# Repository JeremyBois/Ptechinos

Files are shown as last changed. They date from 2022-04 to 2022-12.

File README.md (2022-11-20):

# Ptechinos
## Description
**Ptechinos** is an ergonomic keyboard inspired by [Pteron36](https://github.com/harshitgoel96/pteron36-split-keyboard) and [Balbuzard](https://github.com/brow/balbuzard):

**Hardware**

  - 36 keys (Kailh choc v1)
    - 5x3 keys layout + 3 thumb keys
    - 2 optional encoders (EVQWGD001) or keys (36 --> 38)
      - Top pinky
      - Above thumbs
    - Outer columns for top pinky
      - L size movement reduce hand torsion
      - Top pinky still available (key or encoder)
    - Small splay to adjust to natural hand shape
    - Columns stagger with extreme pinky stagger

  - Modular
    - I2C components
      - Trackpad (GlidePoint Cirque Trackpad TM035035)
      - OLED screen (Adafruit OLED SSD1306 Monochrome 1.3" 128x64)
      - Any I2C device (like SparkFun Qwiic COM-15168)
        - Interface 1: Qwiic connection
        - Interface 2: Header pins exposed (1x04 with 2.54mm pitch)
    - SPI components (RP2040 only)
      - Trackball (Pixart PMW3360, 25mm ball used)
      - Any SPI device: header pins exposed (2x04 with 1.27mm pitch)

    - Pogo (magnetic) or TRRS to connect both halves
      - TRRS: More option but not safe (shorts, hard to disconnect in case of tear-out)
      - Pogo: Less option but safe (no shorts, safely disconnect in case of tear-out)

    - Split or Unsplit
      - Use magnetic Pogo pins and a central module

  - Bluetooth ready
    - On/Off switch to avoid losing battery
    - JST PH connectors to make it easy to replace the battery
    - MCU board footprint compatible with *Nice!nano* and like
    - Components support is ZMK dependent

**Software**

  - [QMK layout v0.5](https://github.com/JeremyBois/qmk-ptechinos)

***
**Drawings and 3D case design made with love by [pandhara](https://www.artstation.com/pandhara).**
***

# Versions
All production files are in `data/production` :
  - `gerber`: files needed to manufacture the keyboard PCB
  - `plates`: 2D/3D files to build the **sandwich** case
  - `unibody`: 2D/3D files to build the **3D** case (starting from v0.6)

## V0.6 - 🚧

**WORK IN PROGRESS.**

### Changes

  - **PCB**
    - Improve / clean routing
    - Dimensions (hxl): 111x159mm
    - Choc v1 spacing (with 1mm padding)
    - Add support for Serial components:
      - Trackball (Pixart PMW3360)
    - Add support for I2C components:
      - Cirque trackpad with FFC/FPC connector
      - OLED with socketing / QWIIC (Require KP2040)
      - Joystick with QWIIC (Require KP2040)
    - Update guard holes position and add another at the bottom (3 in total)
    - MCU and TRRS are now aligned to PCB top edge and each protrude slightly
    - Add support for [Asymplex ChicagoSteno T15 Thumb](https://www.asymplex.xyz/product/cs-ergo-sets)
      - Change right/left thumbs orientation (+-90°)
      - Increase spacing between thumbs (+5mm)
      - Reduce rotation between thumbs (-5°)
    - Encoders
      - Thumb encoder pins connection change (F5/F4 to D4/C6)
      - Index encoder at the top left as an alternative to thumb encoder
      - Both encoders can be used at the same time
    - Make more space for encoder / optional key for MX keycaps (using [this adapter](https://www.thingiverse.com/thing:4504072))
    - Add Pogo connectors support
      - 4 pins version allows for safer alternative to TRRS (no shorts, disconnect gently)
      - 8 pins version allows to switch between split and unsplit

  - **Sandwich case**
    - Bottom plate
      - Uses 15cm magnet holes
      - Replace standard 1/4 holes by splitkb tenting kit hole
    - Top plate
      - Encoder / Key (above thumbs cluster) excluded from plate

  - **Unibody case**  (WORK IN PROGRESS)
    - 3D case
    - Support for different modules:
      - OLED Adafruit OLED SSD1306 Monochrome (1.3 "128x64)
      - Trackpad GlidePoint Cirque Trackpad TM035035 (35mm flat)
      - Trackball Pixart PMW3360 (25mm ball)
      - Unsplit both parts (Pogo connectors)
      - Bottom plate with 1/4inches and magnets to connect to camera mounts
        - Plate stays on the mount
        - Keyboard clip with magnet to the plate

  - **Misc**
    - Add bill of material (BOM)
    - Add documentation about parts

Left           |  Right
:-------------------------:|:-------------------------:
Left  |  Right

Electrical schema

Orientation

### Bill of materials (BOM)
#### Base
Part name | Amount | Reference sourced | Notes | Links
:------------------------|:-------------------------:|:-------------------------:|:-------------------------|:-------------------------
PCB  | 2 | | See `data/production/v0.6/gerber` folder | [PCBWay](https://www.pcbway.com/), [JLCPCB](https://jlcpcb.com/), ...
*(Optional)* Hot Swap Sockets | 36 | Kailh Choc hotswap sockets | Choc version only | [Splikb](https://splitkb.com/collections/keyboard-parts/products/kailh-hotswap-sockets?variant=39472161456205)
Diodes | 38 | 1N4148_SOD-123 | You can either use through hole or surface mount diodes (SMD) | [Splitkb](https://splitkb.com/collections/keyboard-parts/products/smd-diodes)
Kailh Choc switch | 36 (38) | PG1350 | Only choc switches not MX | [Splitkb](https://splitkb.com/collections/switches-and-keycaps/products/kailh-low-profile-choc-switches)
Encoder horizontal | 1/2 | Panasonic_EVQWGD001 | Both sides on QMK and only the master side on ZMK | [Aliexpress](https://fr.aliexpress.com/item/1005003613012575.html)
*(Optional)* Tactile push button | 1/2 | 1TS002A-2500-4300 | Can be replaced with a pair of tweezer or using on board push buttons if any | [Splitkb](https://splitkb.com/collections/keyboard-parts/products/reset-buttons?variant=42291963527427)
*(Optional)* Tenting puck | 1/2 | Splitkb_TentingPuck | 1/4th inch threaded tripod mounting hole | [Splitkb](https://splitkb.com/products/tenting-puck)

#### Bluetooth
Part Name | Amount | Reference sourced | Notes | Links
:------------------------|:-------------------------:|:-------------------------:|:-------------------------|:-------------------------
Battery | 2 | DEAH 301030 | This size could fit under the microcontroller but be free to order another one | [Aliexpress](https://fr.aliexpress.com/item/1005003635594999.html)
*(Optional)* On/Off switch | 2 | TLZWLA_MSK22D18<br>NewRise_MSS22D18 | Allow to turn off the battery power drain during transport | [Aliexpress](https://fr.aliexpress.com/item/4000681551007.html)<br>[Aliexpress](https://fr.aliexpress.com/item/32819941320.html)
*(Optional)* Battery JST PH connector | 0/1/2 | S2B-PH-K-S(LF)(SN) | You can also solder the battery directly to the pins of the PCB | [Splitkb](https://splitkb.com/products/wireless-controller-expansion-bundle)
Nice!nano | 2 | | Cannot be used with QMK due to license issues but works with ZMK | [Splitkb](https://splitkb.com/collections/keyboard-parts/products/nice-nano)
*(Optional)* Decoupling capacitor 4.7uF | 2 | Samsung Electro-Mechanics CL21A475KPFNNNE  | The capacitors mitigate power surge when turning on the battery (already present on Nice!nano boards) | [Mouser](https://eu.mouser.com/ProductDetail/Samsung-Electro-Mechanics/CL21A475KPFNNNE?qs=yOVawPpwOwmSlN4VFiPp3g%3D%3D)

#### Wired
Part Name | Amount | Reference sourced | Notes | Links
:-------------------------|:-------------------------:|:-------------------------:|:-------------------------|:-------------------------
TR(R)S cable | 1 | TRRS | Both TRS or TRRS will work but only tested with a TRRS | [Splitkb](https://splitkb.com/collections/keyboard-parts/products/braided-trrs-cable)
TRRS connectors  | 2  | PJ-320A | | [Splikb](https://splitkb.com/collections/keyboard-parts/products/trrs-jacks)
MCU board with ProMicro footprint | 0/2 | Adafruit_KP2040-RP2040 | ProMicro ATmega32u4 (AVR) <br>EliteC ATmega32u4 (AVR)<br>SparkFun Pro Micro - RP2040 (ARM)<br>Adafruit KP2040 - RP2040 (ARM) | [Splitkb](https://splitkb.com/collections/keyboard-parts/products/pro-micro-atmega32u4-5v-16mhz)<br>[Splitkb](https://splitkb.com/collections/keyboard-parts/products/elite-c-low-profile-rev4-microcontroller)<br>[Mouser](https://eu.mouser.com/ProductDetail/SparkFun/DEV-18288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)<br>[Adafruit](https://www.adafruit.com/product/5302)

#### Trackpad
Part Name | Amount | Reference sourced | Notes | Links
:-------------------------|:-------------------------:|:-------------------------:|:-------------------------|:-------------------------
Cirque trackpad | 1/2 | Cirque_TM035035-2024-002 | Unibody case required 35mm version but any size would work on the sandwich case | [Mouser](https://eu.mouser.com/ProductDetail/355-TM0350352024-002)
FFC jumper cable | 1/2 | Molex_15166-0123 | One on each side where a trackpad is added | [Mouser](https://eu.mouser.com/ProductDetail/538-15166-0123)
FPC connector | 1/2 | GCT_FFC2B35-12-G | One on each side where a trackpad is added | [Mouser](https://eu.mouser.com/ProductDetail/640-FFC2B35-12-G)
4.7kΩ Resistor (I2C) | 2/4 | Panasonic_ERA-6AEB472V | 2 Pull-up resistors for I2C connection are required at least on the master side | [Mouser](https://eu.mouser.com/ProductDetail/667-ERA-6AEB472V)

#### OLED screen
Part Name | Amount | Reference sourced | Notes | Links
:-------------------------|:-------------------------:|:-------------------------:|:-------------------------|:-------------------------
SSD1306 OLED 128x32 | 1/2 | | Works with both ARM and AVR MCU on QMK | [Splitkb](https://splitkb.com/collections/keyboard-parts/products/oled-display?variant=31716335616077)
4.7kΩ Resistor (I2C) | 2/4 | Panasonic_ERA-6AEB472V | 2 Pull-up resistors for I2C connection are required at least on the master side | [Mouser](https://eu.mouser.com/ProductDetail/667-ERA-6AEB472V)

#### 3D case
Part Name  | Amount | Notes | Links
:-------------------------|:-------------------------:|:-------------------------|:-------------------------
Top plate | 2 | See `data/production/v0.6/unibody` folder for DXF / STL files |
3D Case (left) | 1 | See `data/production/v0.6/unibody` folder for DXF / STL files |
3D Case (right) | 1 | See `data/production/v0.6/unibody` folder for DXF / STL files |
M2 Screws | 16 |  For M2 spacers | [Splitkb](https://splitkb.com/products/m2-screws?variant=42429972709635)
M2 Case Spacers | 10 | 6mm works fine (PCB = 1.6mm, PCB to switch  = 2.2mm, socket = 1.8mm) | [Splitkb](https://splitkb.com/products/brass-m2-spacers?_pos=2&_sid=9df1e01bc&_ss=r)
M2 Guard Spacers | 6 | TODO |

#### Sandwich case
Part Name  | Amount | Notes | Links
:-------------------------|:-------------------------:|:-------------------------|:-------------------------
Top plate  | 2 | See `data/production/v0.6/plates` folder for DXF / STL files |
Bottom plate  | 2 | See `data/production/v0.6/plates` folder for DXF / STL files |
M2 Screws | 16 |  For M2 spacers | [Splitkb](https://splitkb.com/products/m2-screws?variant=42429972709635)
M2 Case Spacers | 10 | 4/6mm works fine depending of the length of used M2 screws| [Splitkb](https://splitkb.com/products/brass-m2-spacers)
M2 Guard Spacers | 6 | TODO |

## V0.5 - ✅

  - Update Ergogen config
    - automatic plates generation (2d/3d)
    - remove PCB components (unused)
    - add bottom magnets / camera mounts holes
    - add preview drawing to make easier to visualize plates stack
  - Update PCB board constraints with more aggressive minimums
  - Update PCB according to new Ergogen plate config
  - PCB
    - Improve silkscreens adjustments
    - More aggressive thumb angle
    - Lower thumbs keys
    - Encoder angle is now the same as the thumb key below
    - Update board dimensions
  - Bottom plate uses 15cm magnet holes

Left           |  Right
:-------------------------:|:-------------------------:
Left  |  Right

Electrical schema

Orientation

**Wired version is fully tested** : see used [QMK layout](https://github.com/JeremyBois/qmk-ptechinos).

## V0.4 - ⚰️

  - Update README
    - Add credits
    - Add pictures
    - Add notes for available mask colors
  - Update silkscreen drawings with final version
  - Consistent hole size in switch footprints
  - Generate STL files for plate mounting
  - Make encoder (EVQWGD001) footprint reversible using SMD jumpers
    - Require to bridge jumpers on the same side as the encoder
  - Bottom plate uses 10cm or 15cm magnet holes

**Untested.**

## V0.3 - ⚰️

  - Replace vertical encoder (EC11) with horizontal one (EVQWGD001)
  - Better tracing
  - Add teardrops
  - Mounting
    - Correct mounting holes size
    - Add MCU guard holes
    - Complete plates (top / bottom)
  - Add logo to silkscreen (draft)
  - Find keyboard name
  - Bottom plate uses 10cm magnet holes

**Untested.**

## V0.2 - ⚰️

  - Add Bluetooth components
    - On/off switch
    - Capacitor
    - Battery support
      - JST female to avoid to solder the battery
      - pins also available if soldering is needed/wanted
  - Mounting
    - Add Mounting holes (draft)
    - Add plates (draft)

**No production files.**

## V0.1 - ⚰️

  - 36 keys + 2 optional encoders (EC11)
  - Pro micro footprint
  - TRRS / TRS jack to connect both halves
  - Reset

**No production files.**

# Notes
## v0.5 VS v0.6
Distance              | v0.6            | v0.5             | Result    |
|---------------------|-----------------|------------------|-----------|
Top to FarThumbs      | [69.31, 88.91]  | [70.905, 93.735] |  [✅, ✅] |
Top to InnerThumbs    | [28.970, 67.89] | [31.885, 72.075] |  [✅, ✅] |
Encoder to HomeThumbs | [ , 3.432]      | [ ,    4.096]    |  [  , 😑] |
Top to OuterPinky     | [58.57, 37.64]  | [59.665, 40.315] |  [✅, ✅] |
Home to HomeThumbs    | [30.11, 52.55]  | [32.246, 54.7]   |  [✅, ✅] |

## v0.5 VS v0.66
Distance              | v0.66            | v0.5             | Result    |
|---------------------|-----------------|------------------|-----------|
Top to FarThumbs      | [70.04, 87.98]  | [70.905, 93.735] |  [✅, ✅] |
Top to InnerThumbs    | [28.83, 67.71]  | [31.885, 72.075] |  [✅, ✅] |
Encoder to HomeThumbs | [ , 3.556]      | [ ,    4.096]    |  [  , 😑] |
Top to OuterPinky     | [57.54, 37.07]  | [59.665, 40.315] |  [✅, ✅] |
Home to HomeThumbs    | [30.456, 52.97] | [32.246, 54.7]   |  [✅, ✅] |

### TODO

  - [x] RP2040 MCU board in a ProMicro footprint
    - More SRAM to enable more stuff (RGB leds, pointing devices, OLED, ...)
    - Better pointing device experience ([smoother trackpad experience](https://www.reddit.com/r/ErgoMechKeyboards/comments/w6r7on/comment/ihfko44/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))
    - **QWIIC** connector for easy to plug I2C devices
    - [x] Find headers perfect height

  - [x] GlidePoint Cirque circular trackpad (I2C)
    - [Secifications](https://www.dropbox.com/s/2l2cywvwxdfnoyw/GP-DS-170409%20TM035035%20SPI-I2C%20PINN%20Trackpad%20Spec.pdf?dl=0)
    - [Schematic](https://www.dropbox.com/s/vk752nkoqo7jbqw/02-000611-00RevA01_TM035035-2024-000_SCH.pdf?dl=0)
    - Trackpad PCB must be adapted to be used with Elite-C MCU
      - Remove **R1** (SPI --> I2C)
      - Remove **R7** and **R8** (3.3V --> 5V VCC)
    - Trackpad PCB must be adapted to be used with KB2040 MCU
      - Remove **R1** (SPI --> I2C)
    - [x] Clear enough space to make possible to use both FFC and Qwiic connectors
    - [x] Make sure pin assignation on FFC connector is correct

  - [x] OLED support (I2C)
    - [QMK support](https://docs.qmk.fm/#/feature_oled_driver?id=basic-configuration)
    - [SSD1306 Monochrome 1.3" 128x64 - QWIIC](https://www.adafruit.com/product/938)
    - [SSD1306 Monochrome 0.96" 128x64 - pins](https://splitkb.com/products/oled-display?variant=31226608549965)
    - [SSD1327 Grayscale 1.5" 128x128 - QWIIC (RP2040 required and no QMK support)](https://www.adafruit.com/product/4741)
    - [x] Qwiic accessible
    - [x] Header pins accessible

  - Bluetooth
    - [x] Remove `VCC_ON` (was used to isolated `VCC` line but most MCU have this as a software feature)
    - [x] Remove redundant B+ and B- pins (ones on the connector foo)
    - [x] Make sure there is enough place for battery JST

  - Pogo
    - [x] Add Pogo magnetic connectors (4 pins) as an alternative for TRRS
      - Can be used to merge both half to create an unsplit keyboard
    - [x] Find Pogo connector (4 pins)
    - [x] Find Pogo connector (8 pins)
    - [x] Check 3D works (unibody case)
      - Works (tested with 4 pins version)

  - PCB indications / information
    - Solder on the bottom side
      - Resistors
      - Capacitor
      - Reset switch
      - Diodes
      - Hotswaps
    - [x] Drawings on silkscreen should be more uniform on stroke thickness

  - Trackball
    - [x] Move Reset below Pogo to make space for SPI interface
    - [x] Add SPI interface (in place of Reset) (8 pins header column)
    - [x] Add SPI interface (8 pins JST SH vertical)
    - [x] Check 3D works (unibody case)
    - [x] Update footprint for sensor
    - Limitations of existing boards
      - Only works with the right side with vertical header
      - Can works on all side if using right angle header (add header width to trackball height ...)

  - Documentation
    - [x] Update reset switch
    - [x] Add missing
      - [x] Resistors
      - [x] Capacitors
      - [x] Pogo
      - [x] Header pins PCB
      - [x] Header pins Trackball
    - [ ] Add Build logs
    - [ ] Add Wiki

  - Software
    - [ ] Handle difference between RP2040 and Atemega32U4 on QMK side
      - Trackball (SPI) only compatible with RP2040

  - Outputs (v0.68)
    - [x] Update PCB / Schema date
    - [x] Regenerate DXF (mm)
    - [x] Regenerate gerbers (inch)
    - [x] Regenerate previews
    - [x] Push gerbers for v0.6 (the ones sent to production)

  - Try
    - [x] [Choc keycaps tilter](https://www.thingiverse.com/thing:5379000)
    - [x] Create [Choc keycaps tilter](https://www.thingiverse.com/thing:5379000) variant with 90° angle (to test on outer pinky)
    - [x] [chicago stenographer](https://www.asymplex.xyz/product/cs-chicago-stenographer-profile) keycaps
    - [x] **QWIIC** as a hotswapable I2C with integrated pull-up resistors
    - [ ] Female Threaded 1/4" Standoffs in Unibody case instead of Splikb tenting puck (smaller hole ...)
    - [ ] [Choc to MX converter](https://www.thingiverse.com/thing:4504072) with custom artisan

## Kicad errors

  - Courtyard FPC connector and jumpers overlap
    - It's ok because both are not used at the same time

  - Courtyard JST PH (bluetooth) and JST SH (trackball) overlap
    - It's ok because both are not used at the same time

  - FPC pins are not connected
    - It's ok because we only use 4 of them (I2C)

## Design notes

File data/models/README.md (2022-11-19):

# CAD models

  - [Diode_1N4148W_SOD123](https://grabcad.com/library/sod123-1)
  - [Capacitor_0805_0.6mm](https://grabcad.com/library/ceramic-capacitor-0805-2012-1)
  - [Resistor_0805](https://grabcad.com/library/resistor-0805-1)
  - [JST_PH_2pins_RightAngle](https://grabcad.com/library/2-pin-jst-connector-right-angle-1)
  - [JST_SH_8pins_Vertical](https://grabcad.com/library/jst-sh-smd-connectors-1)
  - [Pogo_4pins_RightAngle](https://grabcad.com/library/4-pin-magnetic-connector-1)
  - [Pogo_8pins_RightAngle](https://grabcad.com/library/pogo-pin-1)
  - [Switch_AlpsAlpine_SKRKAE](https://tech.alpsalpine.com/j/products/detail/SKRKAEE020/)
  - [Encoder_Panasonic_EVQWGD001](https://grabcad.com/library/panasonic-evqwgd001-encoder-1)
  - [Adafruit_KB2040](https://learn.adafruit.com/adafruit-kb2040/downloads)
  - [TRRS_3.5mm](https://grabcad.com/library/3-5mm-micro-jack-female-trrs-fc68128-connector-audio-1)
  - [Kailh_choc_Hotswap](https://github.com/perigoso/keyswitch-kicad-library/tree/main/source_3d/Switch_Keyboard_Kailh)
  - [Kailh_Choc_V1](https://github.com/perigoso/keyswitch-kicad-library/tree/main/source_3d/Switch_Keyboard_Kailh)
  - [FPC_connector](???)

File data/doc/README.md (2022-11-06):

# Documentation

## Whislist

  - Trackball
    - [x] Ball 25mm
    - [x] Bearing balls 2.5mm zirconium oxide (G5)
    - [x] JST SH connector
    - [ ] Breakout board
      - [3.3V or 5V](https://github.com/Ariamelon/Ogen)
      - Assembly JLCPCB
      - Sensor on aliexpress

  - Others
    - [x] Reset
    - [x] Capacitor
    - Rounded socket strip female (~4.8)

  - Pogo
    - [x] 4 pins magnetic
    - [x] 8 pins

## Case

  - [Trackpad + keyboard](https://www.troykitch.com/2021/06/05/split-keyboard-base.html)
  - [Laptop + keyboard](https://www.reddit.com/r/ErgoMechKeyboards/comments/xkdqk0/split_keyboard_attached_to_roost_stand/)
  - Trackball
   - [Oddball](https://github.com/atulloh/oddball)
   - [Ximi](https://www.reddit.com/r/ErgoMechKeyboards/comments/xhvq3v/ximi_is_near/)
   - [Orb](https://github.com/dpapavas/orb-trackball)
   - [Norne v3](https://www.reddit.com/r/ErgoMechKeyboards/comments/y88hbm/my_attempt_to_make_keyboarding_just_a_bit_weirder/)
  - Tenting
    - [Magnetic legs / case](https://www.reddit.com/r/ErgoMechKeyboards/comments/y1a0iy/new_travel_keyboard_this_time_its_splayed/)
    - [Some examples](https://rmwphd.github.io/tenting.html)

## RP2040

  - QMK
    - [Conversion from Promicro (cocot46plus)](https://zhan.co.nl/posts/2022-08-24-cocot46plus-build-notes/#converting-to-rp2040)
    - [Conversion from Promicro (gherkin)](https://learn.adafruit.com/using-qmk-on-rp2040-microcontrollers?view=all)

  - Trackball
    - [Nano trackball + lot of projects / 3D](https://github.com/jfedor2/rp2040-pmw3360)

## Components
### Adafruit KB2040
  - [Product](https://www.adafruit.com/product/5302)

  - [Tutorial](https://learn.adafruit.com/adafruit-kb2040)

  - QMK support
    - [Pull request](https://github.com/qmk/qmk_firmware/pull/14877)

  - Builds
    - [Unichunky](https://www.reddit.com/r/ErgoMechKeyboards/comments/wizqo8/the_unichunky/)

### Trackball Pixart PMW3360 Motion sensor
  - Breakout board
    - [PMW3360](https://www.tindie.com/products/jkicklighter/pmw3360-motion-sensor)

  - PCB
    - [3.3V](https://github.com/jfedor2/pmw3360-breakout)
    - [3.3V or 5V](https://github.com/Ariamelon/Ogen)
    - [Circular - Charybdis keyboard](https://github.com/Bastardkb/charybdis-pmw-3360-sensor-pcb)

  - Capteur
    - [PMW3360DM-T2QU + Lens](https://aliexpress.com/item/32834829893.html)
    - [PMW3360DM-T2QU + Lens](https://aliexpress.com/item/33056166849.html)
    - [PMW3389DM-T3QU + Lens](https://aliexpress.com/item/32891335998.html)

  - Bearing ball ([Zr02 seems better than Si3n4](https://prokcssmedia.blob.core.windows.net/sys-master-images/hb2/haf/9263251816478/ceramic-bearing-selection-guide.pdf), G5 > G10)
    - [ZrO2  | G5 | 2.5mm](https://aliexpress.com/item/4000852337622.html)
    - [Si3N4 | G5 | >=1.0mm](https://aliexpress.com/item/1005004242351539.html)

  - Ball
    - [25mm | billiard](https://www.amazon.com/CAOREN-16pcs-Billiard-Children-Accessories/dp/B0836WQQF5)
    - [34mm | ](https://www.amazon.fr/Perixx-PERIPRO-303-GBK-34mm-Trackball/dp/B08DD6GQRV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)
    - [25mm | stones](https://aliexpress.com/item/1005003604499161.html)

  - CAD
    - [Oddball project](https://github.com/atulloh/oddball)
      - PMW3360 cover
      - Bearing mount
    - [Orb](https://github.com/dpapavas/orb-trackball)
      - [reddit](https://www.reddit.com/r/ErgoMechKeyboards/comments/xziw1u/the_orb_a_parametric_trackball_with_btu_mounted/)
      - PMW3389 cover
      - Bearing mount
      - Compact with buttons

### GlidePoint Cirque Trackpad TM035035
  - QMK support
    - [Trackpad](https://github.com/qmk/qmk_firmware/blob/master/docs/feature_pointing_device.md)
    - [I2C wiring](https://docs.qmk.fm/#/feature_split_keyboard)
    - Trackpad PCB must be adapted to be used with KB2040
      - Remove **R1** (SPI --> I2C)

  - Documentation
    - [Secifications](https://www.dropbox.com/s/2l2cywvwxdfnoyw/GP-DS-170409%20TM035035%20SPI-I2C%20PINN%20Trackpad%20Spec.pdf?dl=0)
    - [Schematic](https://www.dropbox.com/s/vk752nkoqo7jbqw/02-000611-00RevA01_TM035035-2024-000_SCH.pdf?dl=0)

  - Builds
    - [On corne](https://beekeeb.com/cirque-trackpad-i2c-on-corne-keyboard/)
    - [On Chunky V2](https://kbd.news/Chunky-V2-1219.html)

### Adafruit OLED SSD1306 Monochrome 1.3" 128x64
  - [Product](https://www.adafruit.com/product/938)

  - QMK support
    - [OLED](https://docs.qmk.fm/#/feature_oled_driver?id=basic-configuration)
    - [I2C wiring](https://docs.qmk.fm/#/feature_split_keyboard)

### Joystick SparkFun Qwiic (COM-15168)
  - [Product](https://www.sparkfun.com/products/15168)
    - **Seems to not be available in France at least on Mouser**

  - QMK support
    - [Joystick](https://github.com/qmk/qmk_firmware/blob/master/docs/feature_joystick.md)
      - Can use I2C and send HID data to computer (ADC not required and not supported yet on QMK)
      - ADC does not yet works on QMK with RP2040
    - [I2C wiring](https://docs.qmk.fm/#/feature_split_keyboard)

### Switches
  - Reset
    - [SKRKAEE020_ALPS | x30](https://aliexpress.com/item/1005004196388006.html)
    - [4x3x2           | x100](https://aliexpress.com/item/1005001298009129.html)
  - On/Off
    - [100 | MSK12C02 Power switch](https://aliexpress.com/item/4001295557976.html)
  - Tactile for mouse buttons
    -  [Tact switches](https://en.jian-fu.com/product/48.html)

### Connectors
  - Laptop battery connector
    - [3-12 | 2.54P](https://aliexpress.com/item/1005003903158555.html)
  - Magnetic Pogo
    - [2-4  | 2.54P  |         All](https://aliexpress.com/item/1005003839133752.html)
    - [4    | 2.54P  | All + cable](https://aliexpress.com/item/4000364283897.html)
    - [4    | 2.54P  | Right angle](https://aliexpress.com/item/1005002581987513.html)
  - Pogo
    - [2-10 | 2.54P  | Right angle](https://aliexpress.com/item/1005003579709688.html)
    - [4    | 2.54P  | SMD        ](https://aliexpress.com/item/1005001805224245.html)
  - JST SH
    - [2-12 | M/F | V/H](https://aliexpress.com/item/4001122482484.html)
    - [2-10 | M/F | V/H](https://aliexpress.com/item/1005003131441676.html)
    - [2-10 | Mx2 |     | Wire](https://aliexpress.com/item/1005001295609035.html)
    - [2-10 | M/F | V/H | Wire](https://aliexpress.com/item/32833673778.html)
    - [2-10 | M/F | H   | Wire](https://aliexpress.com/item/4000898605030.html)
    - [2-10 | F   | V  ](https://aliexpress.com/item/1005001783096367.html)
  - JST PH
    - [2-10 | M/F | H   | Wire](https://aliexpress.com/item/4000091077742.html)

### Others
  - Socket strips
    - [Squared | female | 4.57 or 5.08](https://www.mouser.fr/ProductDetail/Samtec/CES-104-01-L-S?qs=PB6%2FjmICvI1cSb0fQjZcig%3D%3D)
    - [Rounded | female | 4.7](https://www.mouser.fr/ProductDetail/Samtec/CES-104-01-L-S?qs=PB6%2FjmICvI1cSb0fQjZcig%3D%3D)
  - Male header right angle (Trackball pins)
    - [Sparkfun](https://www.sparkfun.com/products/553)
  - Capacitors
    - [0805 | 0.5pF - 47uF](https://aliexpress.com/item/32964553793.html)

## Tools
  - [Ergogen (online)](https://ergogen.cache.works/)
  - [OpenScad](https://openscad.org/)
  - [Gerber viewer (online)](https://www.gerberviewer.io/view)

## References

  - [Dilemma](https://kbd.news/Dilemma-keyboard-1557.html)
  - [UniChunky](https://kbd.news/UniChunky-1579.html)
  - [Santoku](https://kbd.news/Santoku-Gen-2-842.html)
  - [Pteron36](https://github.com/harshitgoel96/pteron36-split-keyboard)
  - [Buzzard](https://github.com/crehmann/Buzzard)

## PCB manufacturing
  - [Comparator](https://pcbshopper.com/)
  - [PCBWay](https://www.pcbway.com/orderonline.aspx)
  - [Elecrow](https://www.elecrow.com/pcb-manufacturing.html)

### PCB/Solder Mask Colors
HackADay

A detail description of available colors for PCB manufacturing by [Ben Vallack](https://www.youtube.com/watch?v=3PSUh6gRJk8).
Following colors can be used to get a correct approximation (without the gloss effect):

  - Yellow = `#D5B619`
  - Blue = `#213754`
  - Red = `#cc0000`
  - White = `#A7B5C2`
  - Black (matte) = `#353B3E`
  - Black (gloss) = `#131718`
  - Green (matte) = `#006F52`
  - Green (gloss) = `#005A44`
  - Copper Pad (gloss grey) = `#AFAF98`
  - Purple = `#4b0082`

## Keycaps
  - [Asymplex](https://www.asymplex.xyz)

## Utilities
  - [Binding barrels](https://www.mcmaster.com/binding-barrels/)
  - [Female Threaded Hex Standoffs ](https://www.mcmaster.com/standoffs/thread-size~1-4-20/length~1-4/)
  - [Choc to MX converter](https://www.thingiverse.com/thing:4504072)

## Mounting system

  - [Modular Mounting System](https://www.thingiverse.com/thing:2194278)

## Notes
### Qwiic / STEMMA QT

These connectors have a [1mm pitch](https://learn.adafruit.com/introducing-adafruit-stemma-qt/what-is-stemma-qt) and generic name is **4 pins JST SH** (A larger and more common version is JST PH with 2mm pitch).

### I2C and pull-up
  - [I2C tutorial](https://learn.sparkfun.com/tutorials/i2c)
  - [Good explanation of I2C pull-up resistors](https://www.bluedot.space/tutorials/how-many-devices-can-you-connect-on-i2c-bus/)
    - The I2C bus specification defines a maximum of *0.4V* for the low-level output voltage
    - Multiple devices can be on the same line if pull-up resistors are big enough

$$
\begin{aligned}
& R_{VCC} = \frac{VCC - 0.4}{3mA} \\\\
& R_{5} = \frac{5 - 0.4}{3} = 1.53kΩ \\\\
& R_{3.3} = \frac{3.3 - 0.4}{3} = 967Ω
\end{aligned}
$$

  - By connecting each device in parallel we decreased by the same amount the total resistance

  - Ptechinos use 4.7kΩ resistors for the second I2C line (SDA1 / SCL1)
    - 4.7kΩ resistors on 3.3V VCC allows up to $4$ devices ($\frac{1}{\frac{4}{4.7}} = 1.175kΩ$)

  - [SSD1306 Monochrome 1.3" 128x64 - QWIIC](https://www.adafruit.com/product/938)
    - Include with [2K resistors](https://cdn-shop.adafruit.com/datasheets/UG-2864HSWEG01+user+guide.pdf)
    - Address is software controled allowing multiple screen to be connected on the same bus/line
    - At most 2 screens (($\frac{1}{\frac{2}{2.2}} = 1.1kΩ$)) with a KB2040 board

  - [Sparkfun joystick](https://www.sparkfun.com/products/15168) with QWIIC interface
    - Op-out I2C pullup (2.2kΩ)[](https://cdn.sparkfun.com/assets/7/4/a/6/8/Qwiic_Joystick.pdf)
    - At most 2 joystick (($\frac{1}{\frac{2}{2.2}} = 1.1kΩ$)) with a KB2040 board

  - Qwiic I2C on KB2040 also requires pull-up resistors.

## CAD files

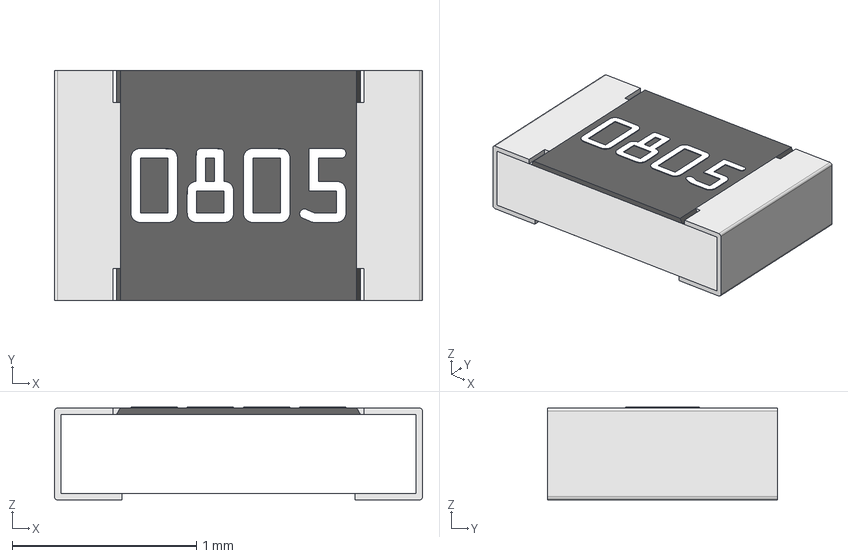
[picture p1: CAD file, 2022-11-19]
data/models/Resistor_0805.step
2.00 x 1.25 x 0.505 mm
Pin1Body
Pin2Body
CeramicBody
CoatingBody
Text1Body
Text2Body
Text3Body
Text4Body

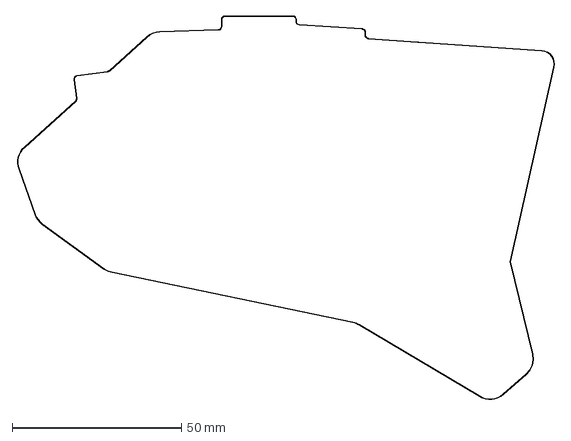
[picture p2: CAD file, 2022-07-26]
data/production/v0.6/data/pcb.dxf
159.2 x 113.8 mm

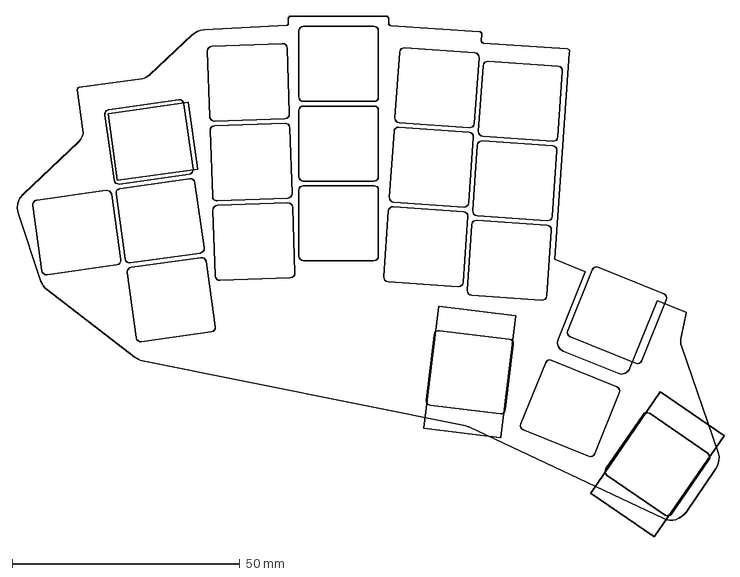
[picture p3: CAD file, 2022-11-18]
data/production/v0.6/kicad/keycaps.dxf
155.6 x 114.4 mm

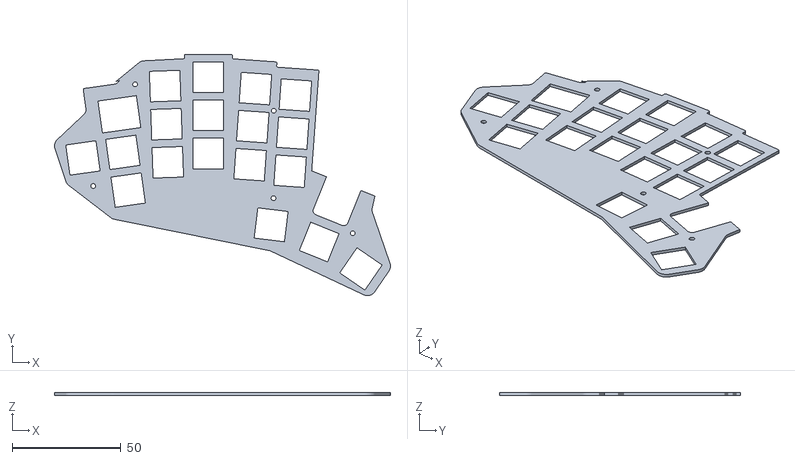
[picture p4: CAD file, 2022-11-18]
data/production/v0.6/plates/top_plate.stl
154.2 x 110.7 x 1.20

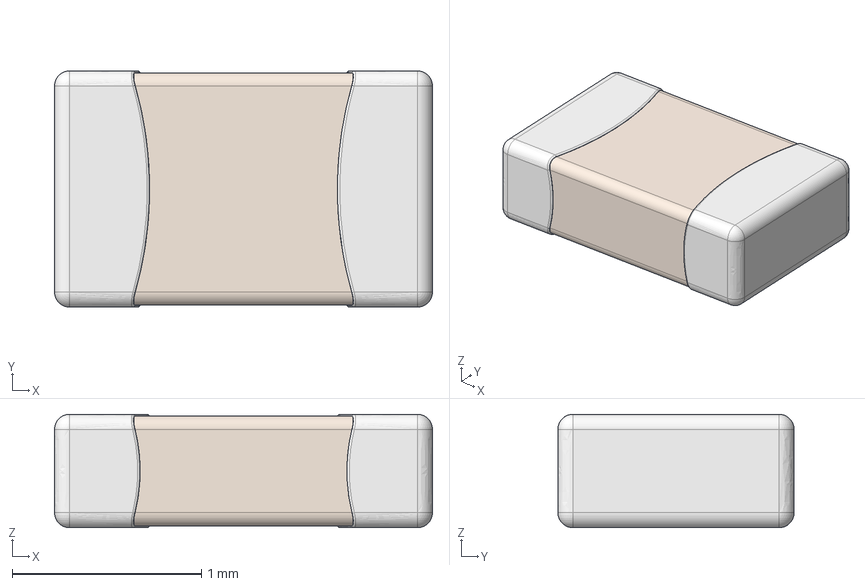
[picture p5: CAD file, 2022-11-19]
data/models/Capacitor_0805_0.6mm.step
2.00 x 1.25 x 0.6 mm
Pin1
Pin2
CeramicBody

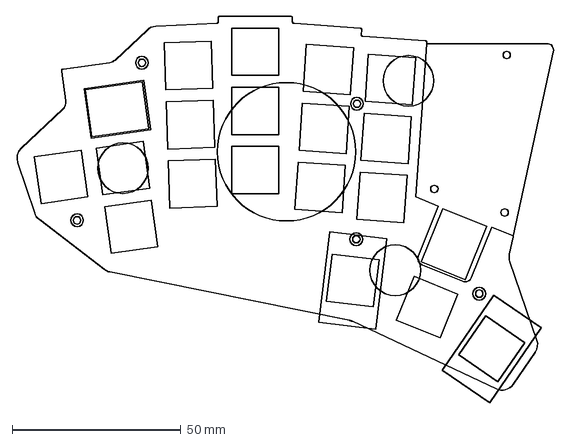
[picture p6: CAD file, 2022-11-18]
data/production/v0.6/kicad/preview.dxf
159.3 x 114.4 mm

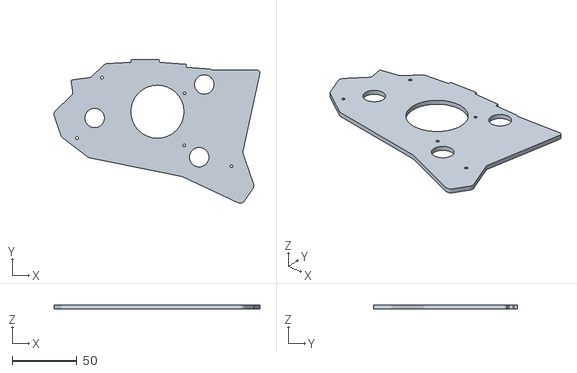
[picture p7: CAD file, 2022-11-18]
data/production/v0.6/plates/bottom_plate.stl
158.9 x 110.7 x 3.00

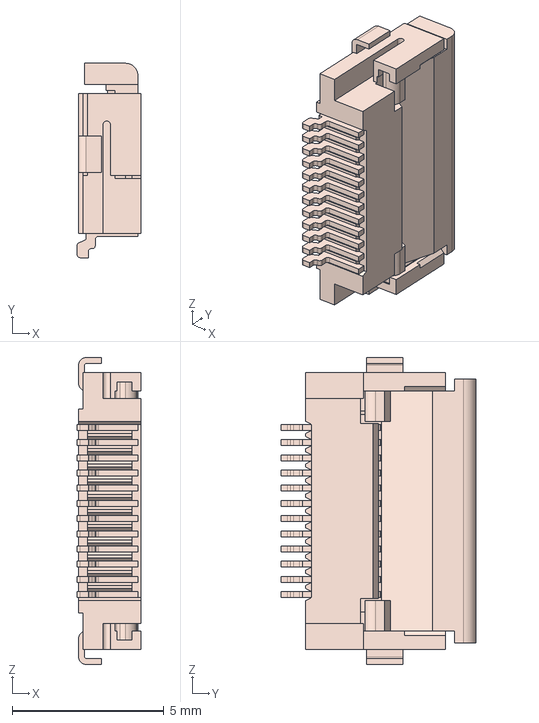
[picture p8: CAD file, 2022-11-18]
data/models/FPC_GCT_FFC2B35-12-G_RightAngle.step
2.10 x 6.40 x 10.1 mm

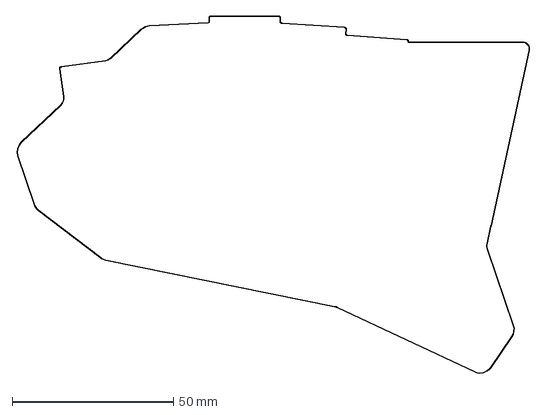
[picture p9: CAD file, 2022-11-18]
data/production/v0.6/kicad/pcb.dxf
159.3 x 111.2 mm

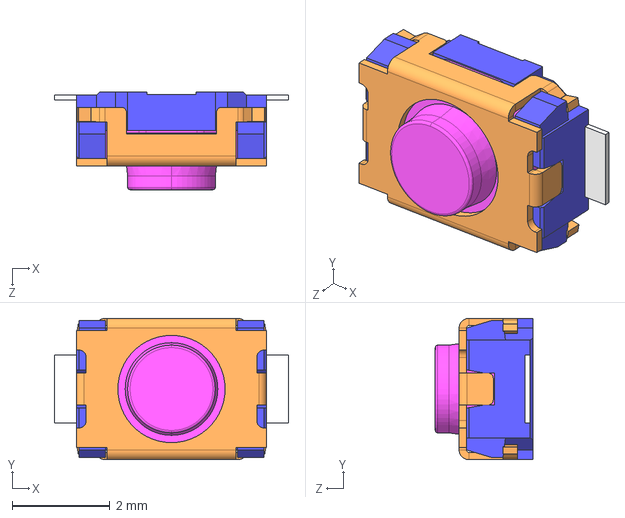
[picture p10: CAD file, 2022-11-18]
data/models/Switch_AlpsAlpine_SKRKAE.step
4.80 x 2.90 x 2.00 mm

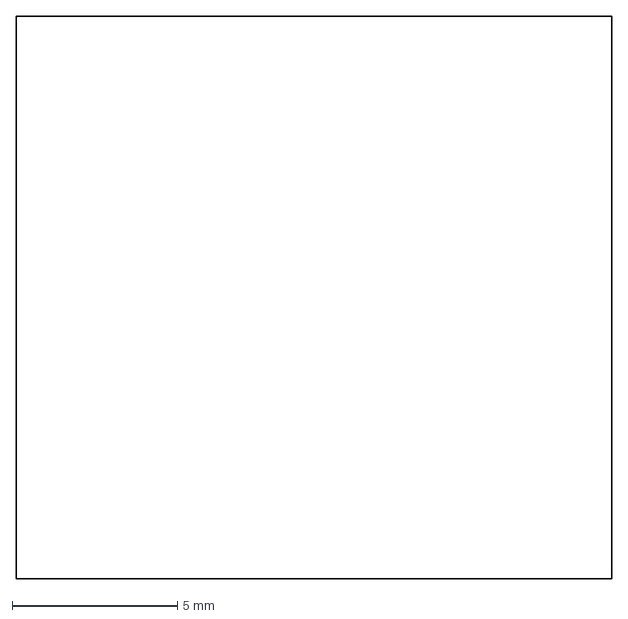
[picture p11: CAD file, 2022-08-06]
data/production/v0.6/kicad/keycap_1u.dxf
18.0 x 17.0 mm

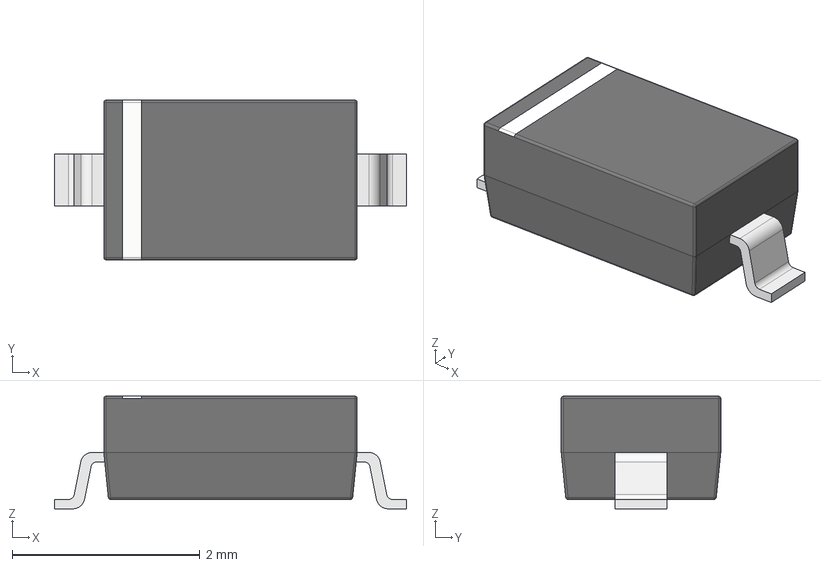
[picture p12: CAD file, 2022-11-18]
data/models/Diode_1N4148W_SOD123.step
3.75 x 1.70 x 1.20 mm
pin
pin(Mirror)
icbody

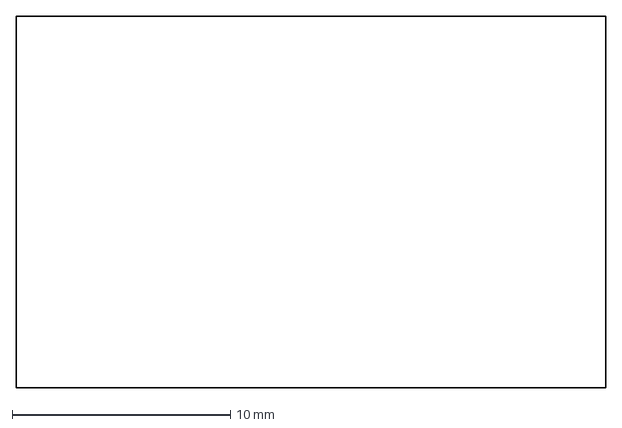
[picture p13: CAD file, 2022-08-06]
data/production/v0.6/kicad/keycap_15u.dxf
27.0 x 17.0 mm

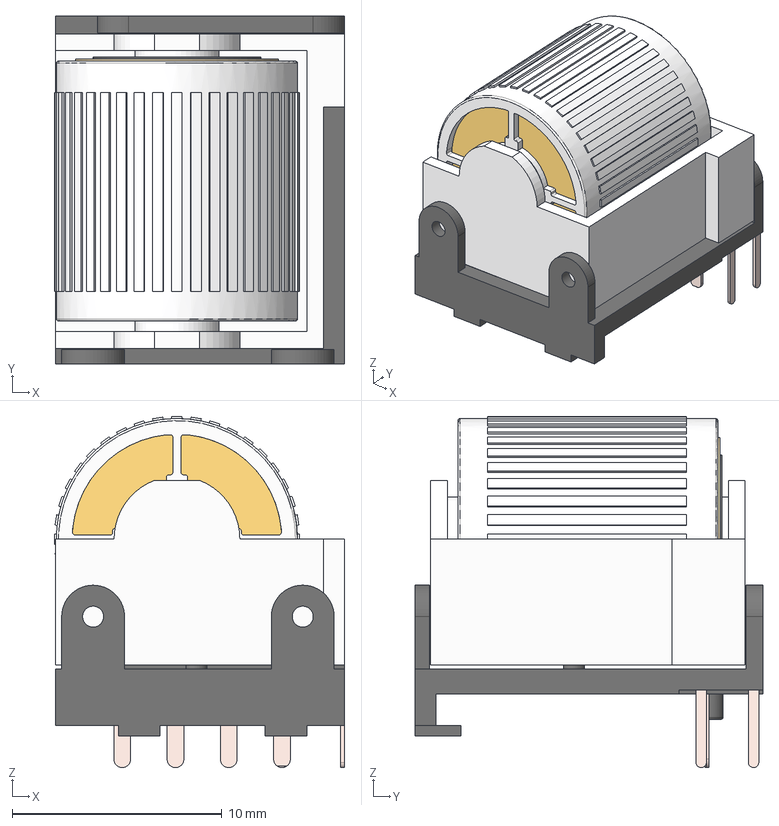
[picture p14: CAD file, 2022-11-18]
data/models/Encoder_Panasonic_EVQWGD001.step
13.9 x 16.6 x 16.8 mm
Plastic
Barrel in
Cap
Barrel out
Leg (1)
housing
Leg (2)
Leg (3)
Plastic (1)
Leg
Leg (4)
Leg (5)

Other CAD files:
data/models/JST_SH_8pins_Vertical.step
data/models/TRRS_3.5mm.step
data/models/Pogo_4pins_RightAngle.step
data/production/v0.3/keycaps.dxf
data/production/v0.3/plates/bottom_plate.dxf
data/production/v0.3/plates/pcb.dxf
data/production/v0.3/plates/top_plate.dxf
data/production/v0.4/keycaps.dxf
data/production/v0.4/plates/bottom_plate.dxf
data/production/v0.4/plates/bottom_plate_10.dxf
data/production/v0.4/plates/bottom_plate_10_3mm.stl
data/production/v0.4/plates/bottom_plate_15.dxf
data/production/v0.4/plates/bottom_plate_15_3mm.stl
data/production/v0.4/plates/pcb_plate.dxf
data/production/v0.4/plates/pcb_plate_1.6mm.stl
data/production/v0.4/plates/top_plate.dxf
data/production/v0.4/plates/top_plate_1.2mm.stl
data/production/v0.5/keycaps.dxf
data/production/v0.5/plates/bottom_plate.dxf
data/production/v0.5/plates/bottom_plate_3mm.stl
data/production/v0.5/plates/pcb.dxf
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

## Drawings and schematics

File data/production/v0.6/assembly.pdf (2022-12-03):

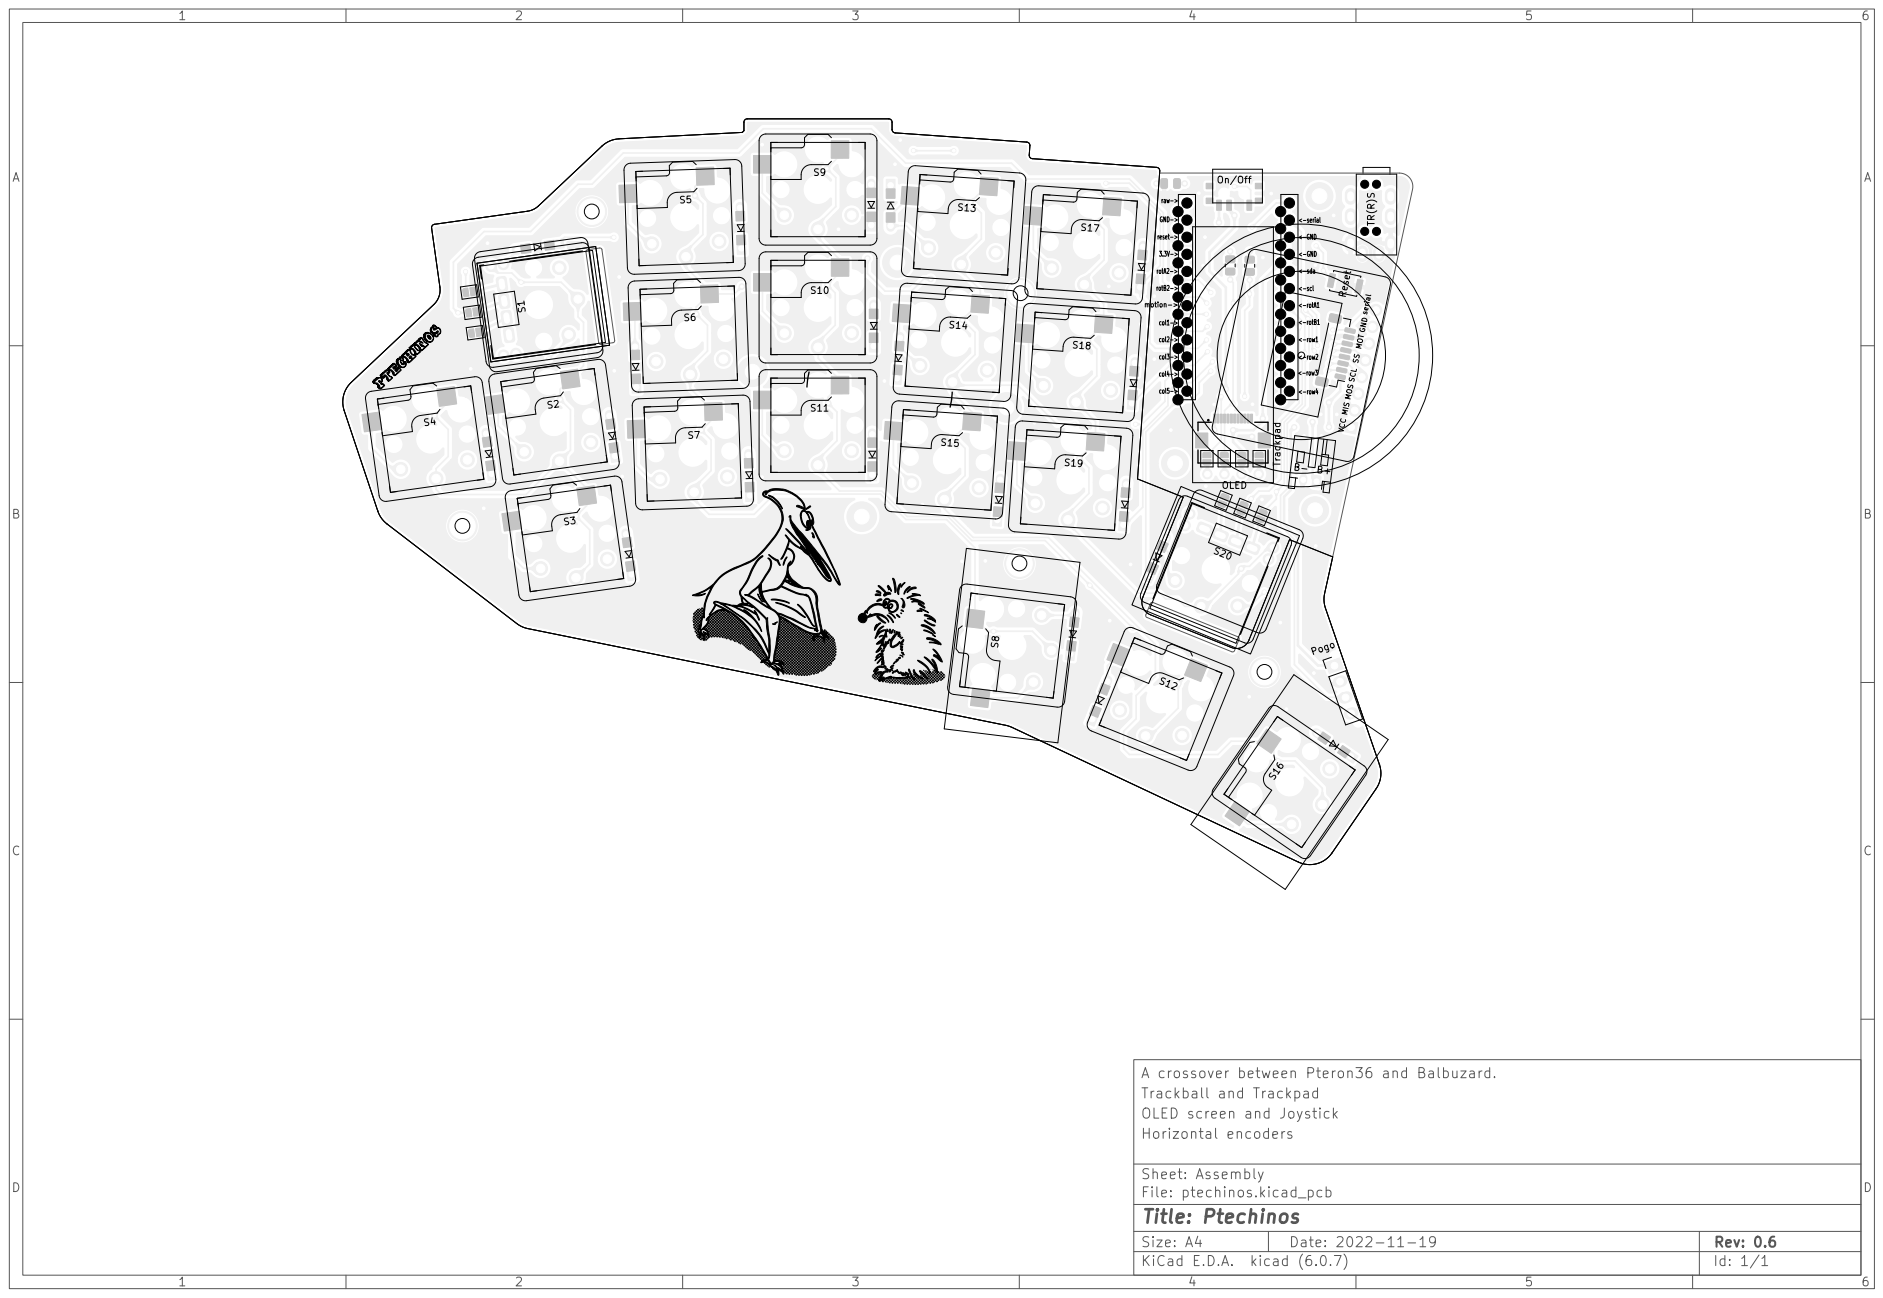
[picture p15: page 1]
S5 S17 S13 S14 S6 S1 Reset; Pogo; <-row4 <-GND; col2->; <-row3 <-row1; reset->; col5->; <-sda; col1->; raw->; <-scl <-row2; rotA2-> motion->; <-serial rotB2->; <-rotB1 GND->; <-rotA1; col4->; <-GND; col3-> S12; On/Off S15 1; 6 ABCD; ABCD Date: 2022-11-19 KiCad E.D.A. kicad (6.0.7) Size: A4; Rev: 0.6

B- B+ S10 S2 S7 S9 S18 Trackpad S8 S20 MOS MOT SCL MIS GND serial SS VCC TR(R)S S3 OLED

Trackball and Trackpad A crossover between Pteron36 and Balbuzard.

Sheet: Assembly Horizontal encoders OLED screen and Joystick

File: ptechinos.kicad_pcb
Id: 1/1 Title: Ptechinos

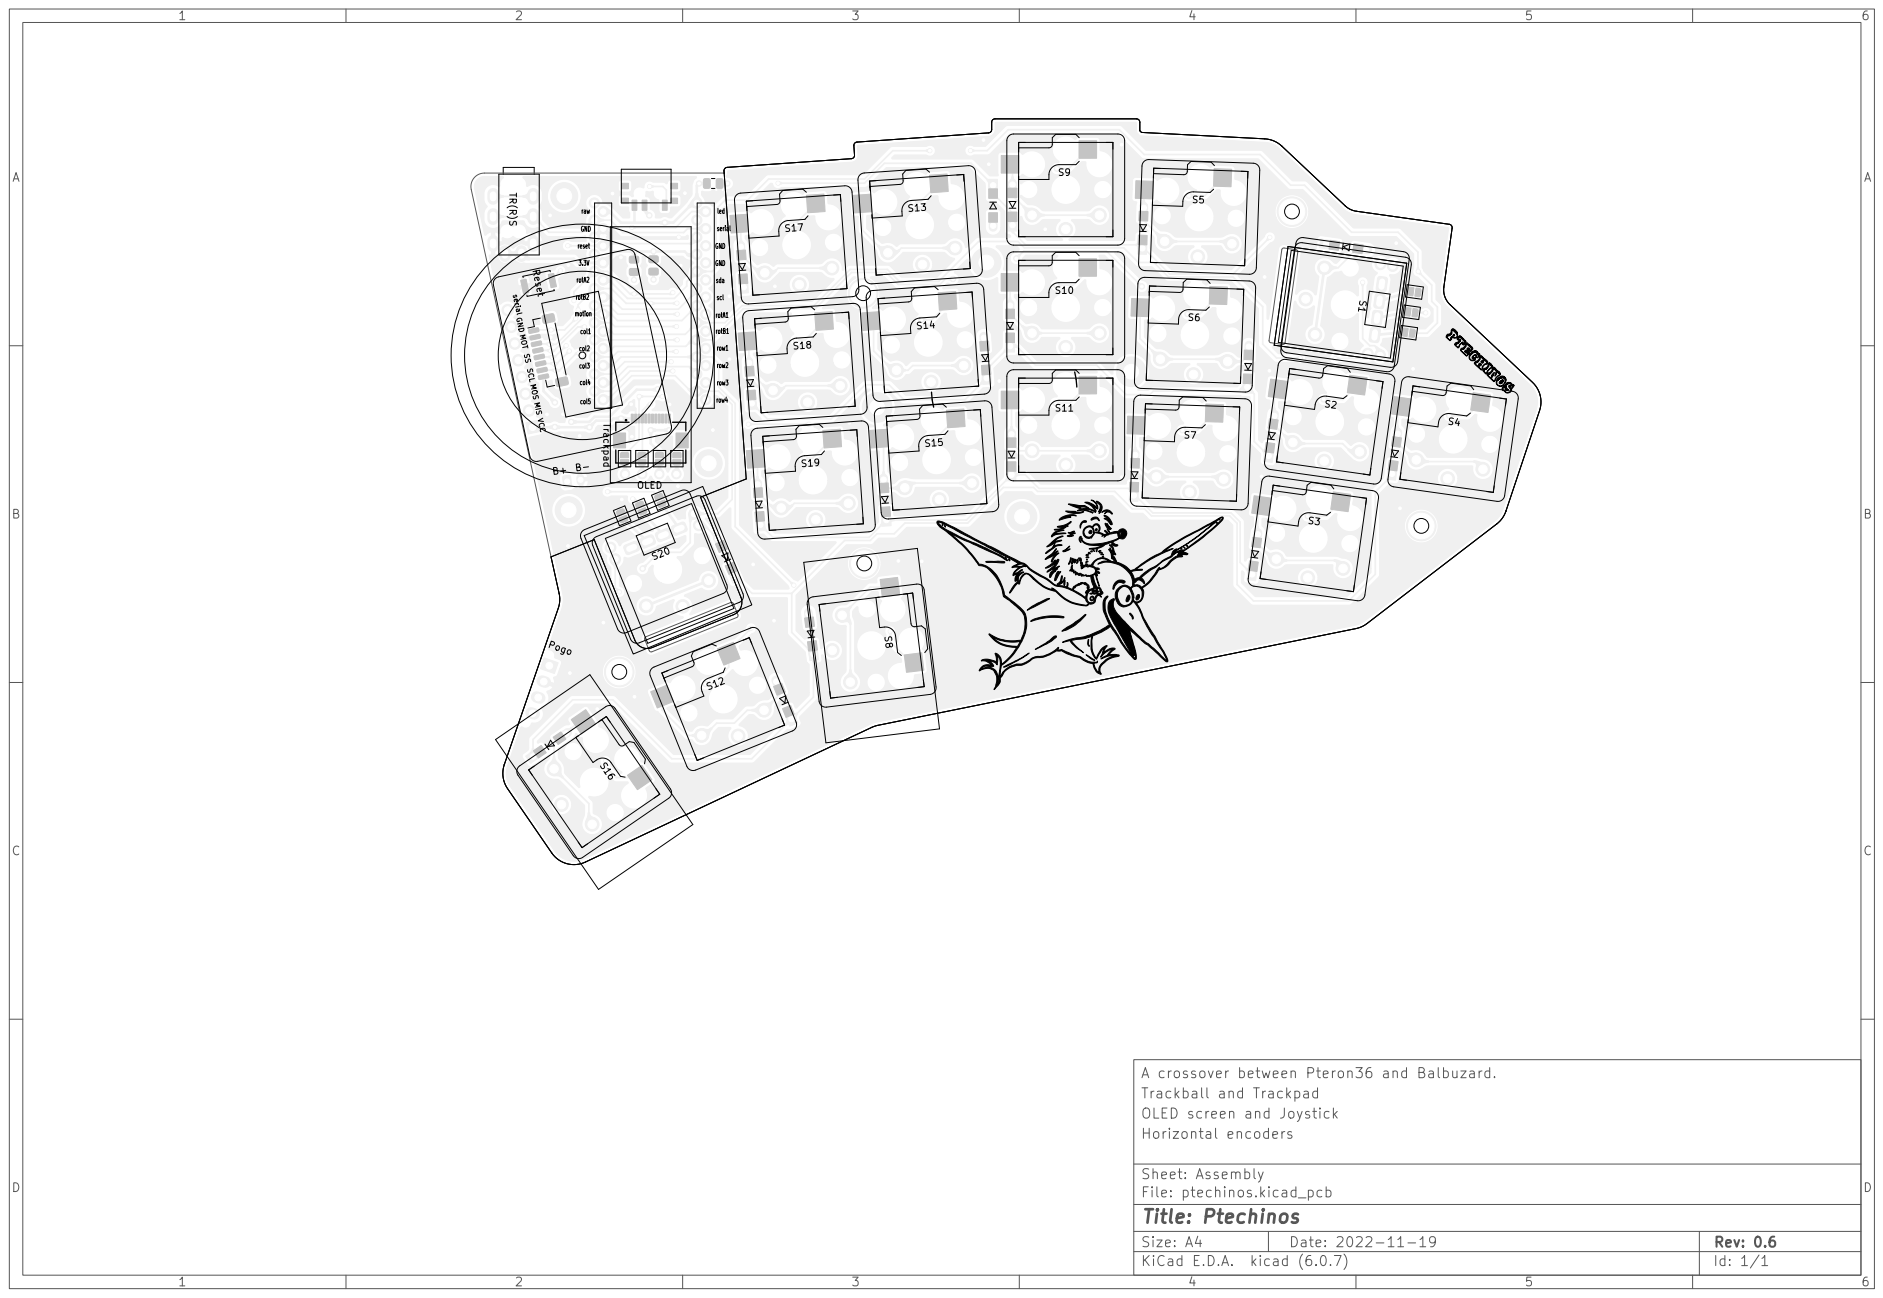
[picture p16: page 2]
S5 S17 S13 S14 S6 S1 S11 S19 S16 S4 Pogo; col4; col3; rotA1; col1; rotB1; row1; serial GND; scl reset; row3; col2; led; sda GND; GND; rotA2 motion; row2; rotB2; raw; row4 S12; S15 Reset 1; 6 ABCD; ABCD Date: 2022-11-19 KiCad E.D.A. kicad (6.0.7) Size: A4; Rev: 0.6

B- col5 B+ S10 S2 S7 S9 S18 Trackpad S8 S20 SS VCC MIS GND MOS serial MOT SCL TR(R)S S3 OLED

Trackball and Trackpad A crossover between Pteron36 and Balbuzard.

Sheet: Assembly Horizontal encoders OLED screen and Joystick

File: ptechinos.kicad_pcb
Id: 1/1 Title: Ptechinos

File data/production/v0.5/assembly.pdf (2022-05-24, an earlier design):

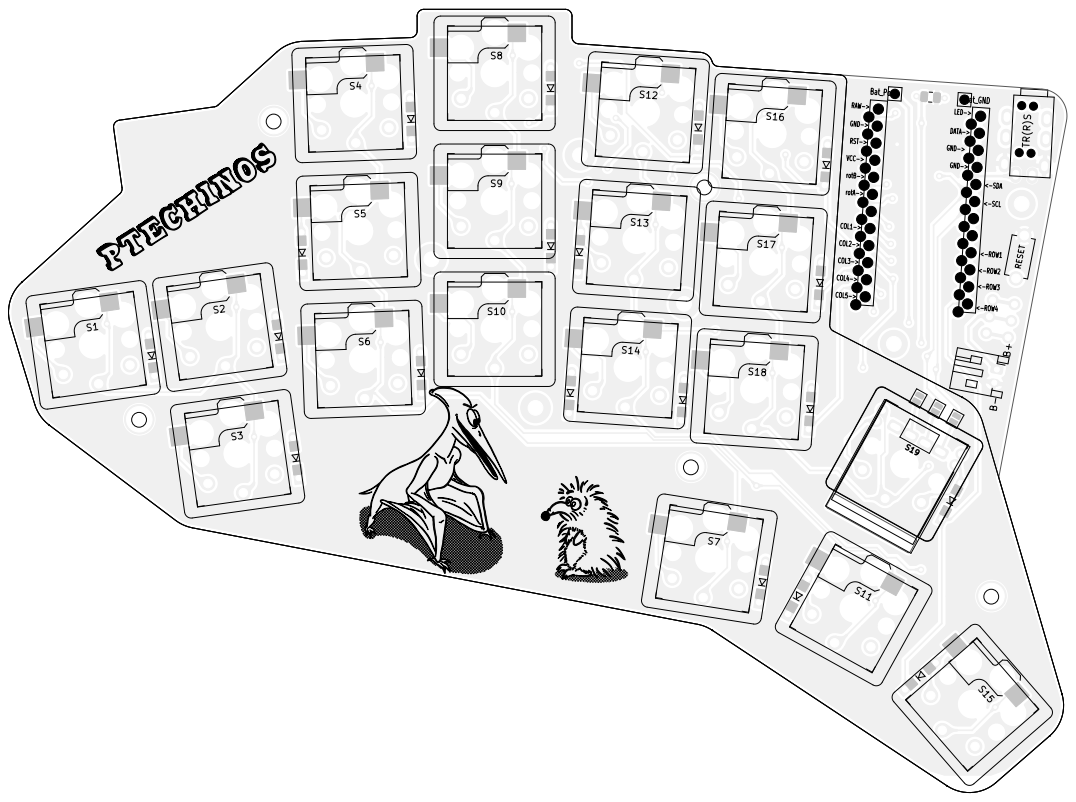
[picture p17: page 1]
Bat_GND S7; RESET S1; Bat_Pos; DATA->; <-ROW1; <-ROW4 VCC->; <-SCL COL2-> LED->; <-SDA

rotA-> S11 S14 1 2 3 4 5 6 1 2 3 4 5 6 ABCD ABCD Date: 2022-05-24 KiCad E.D.A. kicad (6.0.5) Size: A4 Rev: 0.5

rotB-> GND-> COL1-> COL5-> COL3-> RAW-> GND-> RST-> COL4-> <-ROW3 <-ROW2 GND->

Sheet: Assembly A crossover between Pteron36 and Balbuzard.

File: ptechinos.kicad_pcb
Id: 1/1 Title: Ptechinos

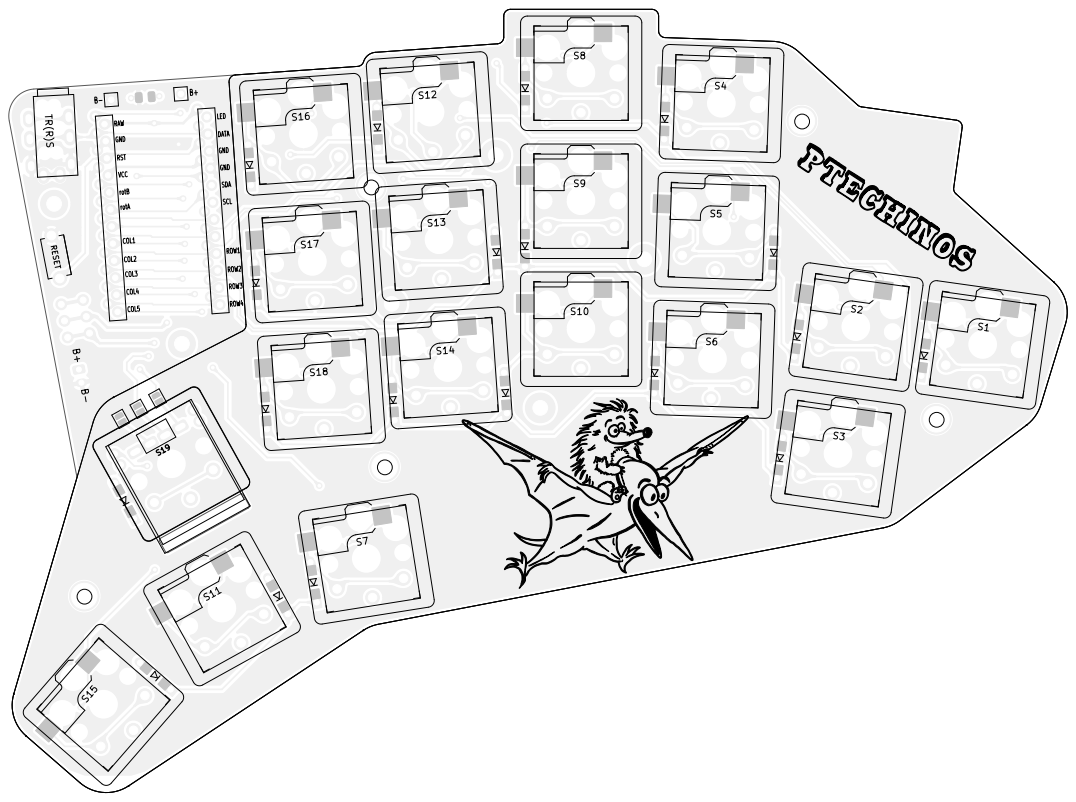
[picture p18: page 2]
RESET; S1 B+ COL5 GND; RST; rotB SDA; ROW1 COL1 LED; COL2 SCL ROW3 VCC; RAW; ROW2; rotA; COL3 COL4 S11 S14; D Date: 2022-05-24 KiCad E.D.A. kicad (6.0.5) Size: A4; Rev: 0.5

ROW4 DATA GND GND

Sheet: Assembly A crossover between Pteron36 and Balbuzard.

File: ptechinos.kicad_pcb
Id: 1/1 Title: Ptechinos

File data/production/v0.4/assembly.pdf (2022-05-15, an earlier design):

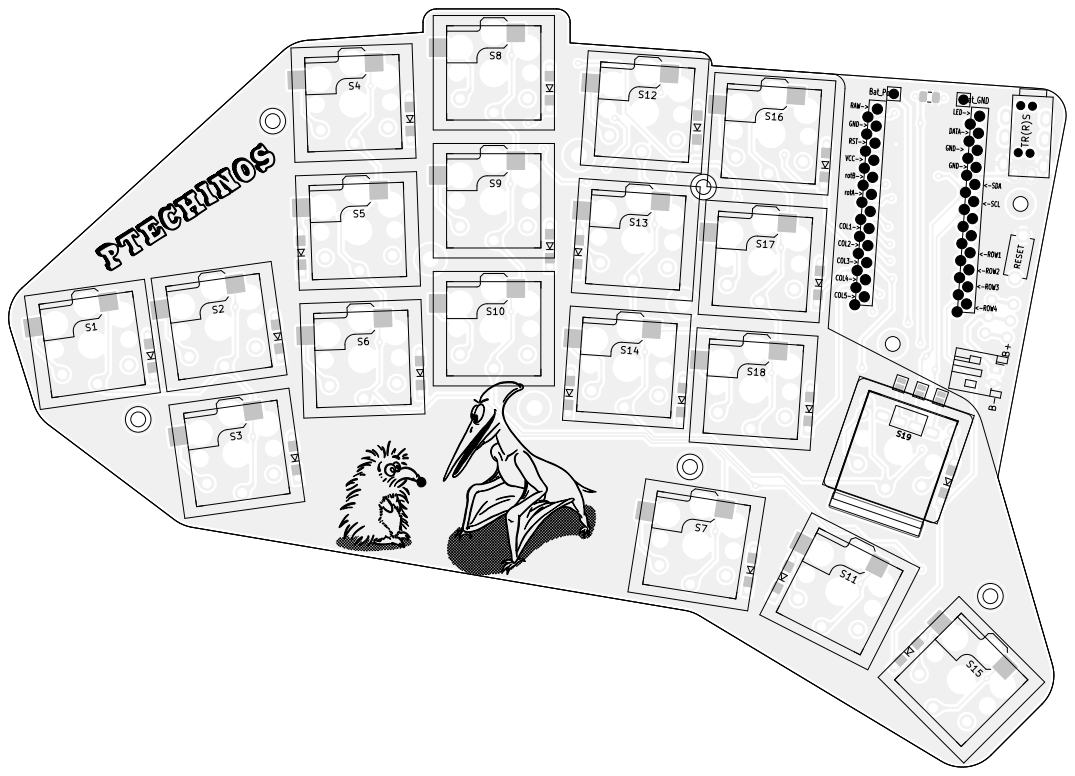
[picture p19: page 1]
Bat_GND S7; RESET S1; Bat_Pos; DATA->; <-ROW1; <-ROW4 VCC->; <-SCL COL2-> LED->; <-SDA

rotA-> S11 S14 1 2 3 4 5 6 1 2 3 4 5 6 ABCD ABCD Date: 2022-05-14 KiCad E.D.A. kicad (6.0.4) Size: A4 Rev: 0.4

rotB-> GND-> COL1-> COL5-> COL3-> RAW-> GND-> RST-> COL4-> <-ROW3 <-ROW2 GND->

Sheet: Assembly A crossover between Pteron36 and Balbuzard.

File: ptechinos.kicad_pcb
Id: 1/1 Title: Ptechinos

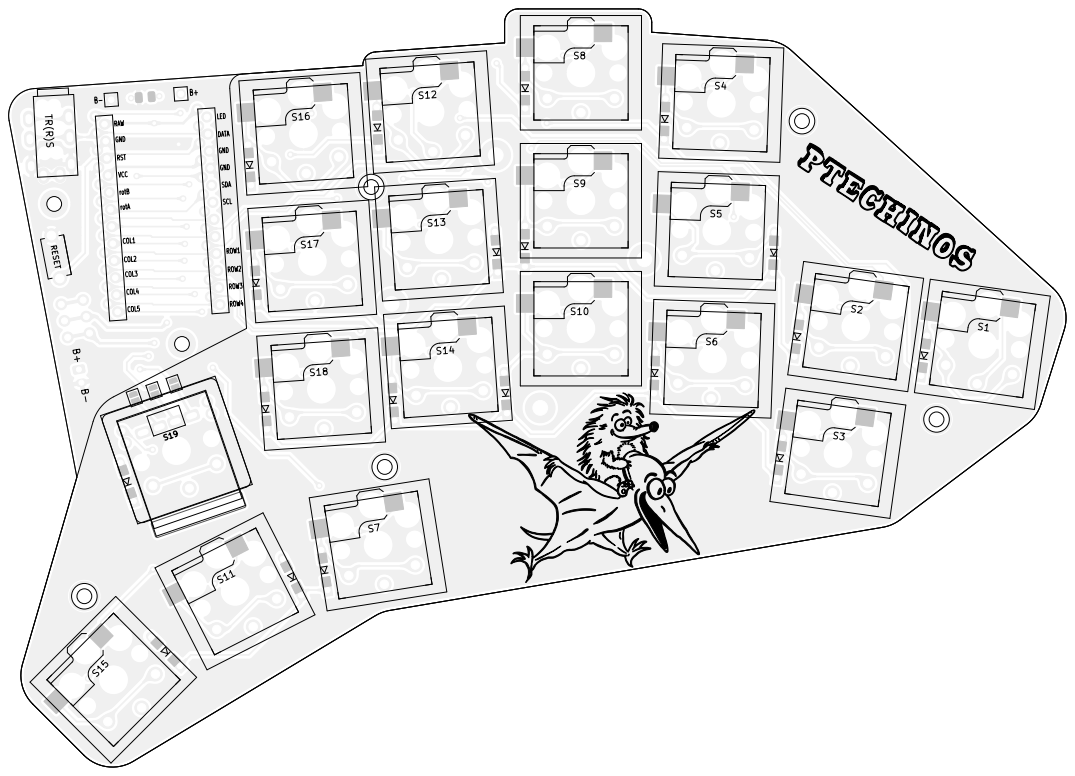
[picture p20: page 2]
RESET; S1 B+ COL5 GND; RST; rotB SDA; ROW1 COL1 LED; COL2 SCL ROW3 VCC; RAW; ROW2; rotA; COL3 COL4 S11 S14; D Date: 2022-05-14 KiCad E.D.A. kicad (6.0.4) Size: A4; Rev: 0.4

ROW4 DATA GND GND

Sheet: Assembly A crossover between Pteron36 and Balbuzard.

File: ptechinos.kicad_pcb
Id: 1/1 Title: Ptechinos

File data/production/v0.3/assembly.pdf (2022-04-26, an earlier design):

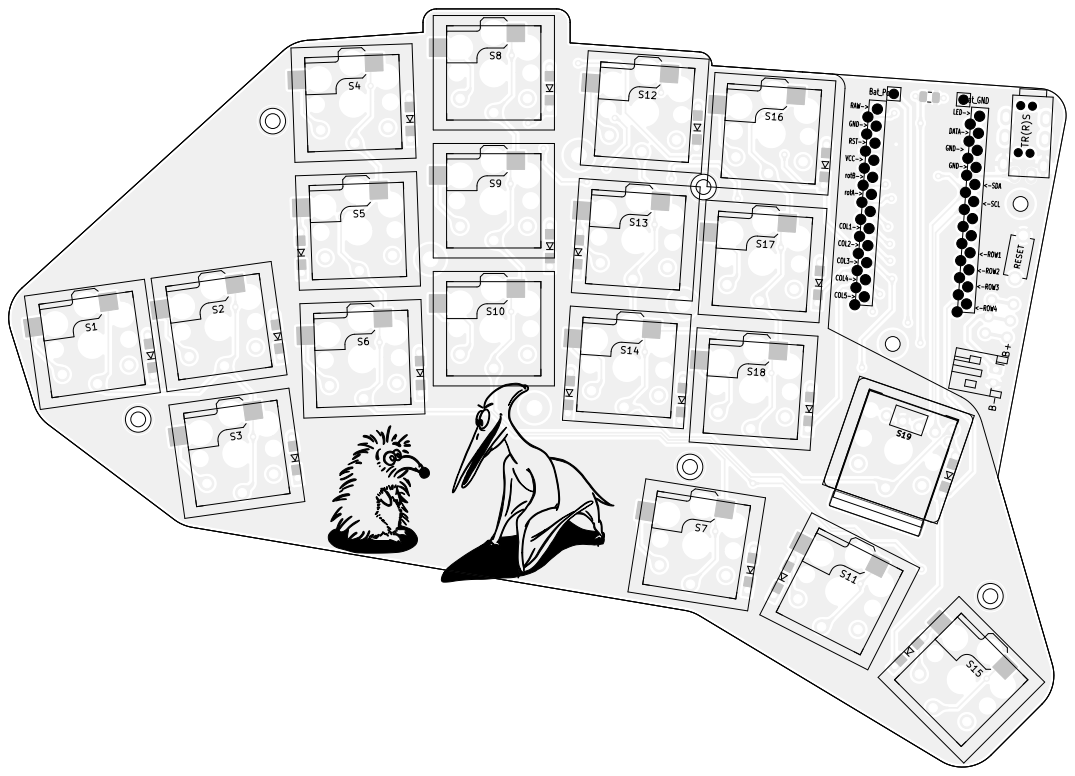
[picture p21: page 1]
Bat_GND S7; RESET S1; Bat_Pos; DATA->; <-ROW1; <-ROW4 VCC->; <-SCL COL2-> LED->; <-SDA

rotA-> S11 S14 1 2 3 4 5 6 1 2 3 4 5 6 ABCD ABCD Date: 2022-04-26 KiCad E.D.A. kicad (6.0.4) Size: A4 Rev: 0.3

rotB-> GND-> COL1-> COL5-> COL3-> RAW-> GND-> RST-> COL4-> <-ROW3 <-ROW2 GND->

Sheet: Assembly A crossover between Pteron36 and Balbuzard.

File: ptechinos.kicad_pcb
Id: 1/1 Title: Ptechinos

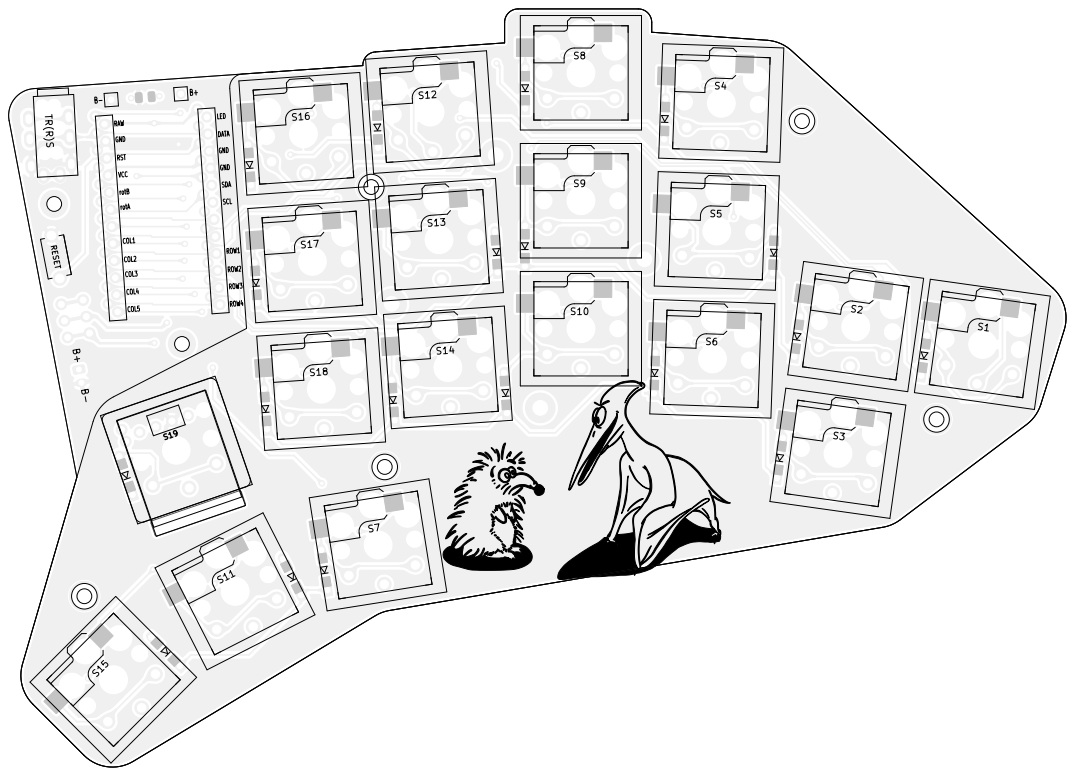
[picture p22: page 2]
RESET; S1 B+ COL5 GND; RST; rotB SDA; ROW1 COL1 LED; COL2 SCL ROW3 VCC; RAW; ROW2; rotA; COL3 COL4 S11 S14; D Date: 2022-04-26 KiCad E.D.A. kicad (6.0.4) Size: A4; Rev: 0.3

ROW4 DATA GND GND

Sheet: Assembly A crossover between Pteron36 and Balbuzard.

File: ptechinos.kicad_pcb
Id: 1/1 Title: Ptechinos

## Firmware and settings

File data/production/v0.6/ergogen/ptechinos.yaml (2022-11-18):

units:
  kx: cx # 18mm Choc spacing
  ky: cy # 17mm Choc spacing
  spreadX: cx + 0.5  # 1mm between caps
  spreadY: cy + 0.5  # 1mm between caps
  capsX: cx - 0.5  # 17.5mm
  capsY: cy - 0.5  # 16.5mm
  px: 2
  py: 2

  # visual_x/_y are built in units
  # keycaps size in demo.dxf
  visual_x: cx
  visual_y: cy
points:
  zones:
    matrix:
      key.padding: spreadY
      columns:
        pinky:
          origin: [ 0, -1ky ]
          stagger: 0 ky
          rotate: 8
          key:
            column_net: P20
          rows:
            top:
              shift: [-spreadX, -spreadY]
              bind: [0, px, 0, 0]
            home:
              shift: [0, 0]
              bind: [3py+ky, 3px, py, 2.5px]
            bottom:
              shift: [0, 0]
              bind: [0, px, 0, 0]
            top_encoder:
              shift: [0, -spreadY]
              bind: [0, px, 0, 0]
        ring:
          origin: [ 0, -1ky ]
          stagger: 0.6 ky
          spread: kx
          rotate: -6
          key:
            column_net: P19
            bind: [0, 2px, py, 0]
        middle:
          origin: [ 0, -1ky ]
          stagger: 0.2 ky
          spread: 0.98spreadX
          rotate: -2
          key:
            column_net: P18
            bind: [py, px, py, px]
        index:
          origin: [ 0, -1ky ]
          stagger: -0.3 ky
          spread: kx
          rotate: -4
          key:
            column_net: P15
            bind: [2.2py, 0, py, 3px]
        inner:
          origin: [ 0, -1ky ]
          stagger: -0.1 ky
          spread: spreadX
          key:
            column_net: P14
            bind: [1.85py, 0.5px, py, px]
      rows:
        bottom:
          row_net: P6
        home:
          row_net: P5
        top:
          row_net: P4
    thumbfan:
      anchor:
        ref: matrix_inner_bottom
        shift: [-1.35kx, -1.68ky]
      columns:
        near:
          spread: spreadX
          origin: [3.6kx, 1.4ky]
          rotate: -3
          key:
            column_net: P19
        home:
          spread: spreadX + 1
          rotate: -15
          origin: [-kx, -0.9ky]
          key:
            column_net: P18
        far:
          spread: spreadX + 1
          rotate: -12.5
          origin: [-kx, -0.9ky]
          key:
            column_net: P15
      rows:
        thumb:
          row_net: P7
    bottom_encoder:
      anchor:
        ref: thumbfan_home_thumb
        shift: [1.9, 1.34ky]
      columns:
        far:
          key:
            column_net: P14
      rows:
        bottom:
          row_net: P6
outlines:
  exports:
    raw:
      - type: keys
        side: left
        size: [kx, ky]
        corner: px
    _glue:
      - type: polygon
        points:
          - ref: thumbfan_far_thumb
            shift: [0.62kx, 0.5 ky]
          - ref: thumbfan_far_thumb
            shift: [0.62kx, -0.5 ky]
          - ref: thumbfan_near_thumb
            shift: [0.5 px, -0.7 ky]
          - ref: matrix_pinky_bottom
            shift: [-0.5kx, -0.71ky]
          - ref: matrix_pinky_bottom
            shift: [-1.53kx, 0.4ky]
          - ref: matrix_pinky_top
            shift: [-0.7kx, 0.5ky]
          - ref: matrix_ring_top
            shift: [-0.6kx, 0.7ky]
          - ref: matrix_ring_top
            shift: [0.5kx, 0.72ky]
          - ref: matrix_ring_top
            shift: [0.51kx, 0.73ky]
          - ref: matrix_ring_top
            shift: [0.52kx, 0.74ky]
          - ref: matrix_inner_bottom
            shift: [39.622, -0.51ky]
          - ref: matrix_inner_bottom
            shift: [39.6, -0.52ky]
          - ref: matrix_inner_bottom
            shift: [38.635, -0.9ky]
    _controller_area:
      - type: polygon
        points:
          - ref: matrix_inner_top
            shift: [0.5555kx, 0.67ky]
          - ref: matrix_inner_top
            shift: [48, 0.826ky]
          - ref: matrix_inner_bottom
            shift: [39.622, -0.51ky]
          - ref: matrix_inner_bottom
            shift: [0.55kx, 0.05ky]
    _bottom_encoder_cutout:
      main:
        type: rectangle
        anchor:
          ref:
            - bottom_encoder_far_bottom
          shift: [-8.5, -11]
        size: [14, 17]
    _top_encoder_cutout:
      main:
        type: rectangle
        anchor:
          ref:
            - matrix_pinky_top_encoder
          shift: [-7.8, -7]
        size: [17, 14]
    _encoder_cutouts:
      - type: outline
        name: _bottom_encoder_cutout
      - type: outline
        name: _top_encoder_cutout
    _top_encoder_exclude:
      main:
        type: rectangle
        anchor:
          ref:
            - matrix_pinky_top_encoder
          # Shift 1 pixel on the right because key not centered
          shift: [-8.05, -7.4]
        size: [17.8, 14.8]
    _bottom_encoder_exclude:
      main:
        type: rectangle
        anchor:
          ref:
            - bottom_encoder_far_bottom
          shift: [-10, -11.75]
        size: [17, 22]
    _encoder_excludes:
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

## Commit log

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2022-04-24 ✨ - Add schematic and PCB files. Version 0.2 fully connected with teardrops.
    [ptechinos.kicad_sch]
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2022-04-26 🍱 - Add draft for logos and remove placeholders. Update graphics footprints with added logos.
    [hedgehog.dxf, pterodactyl.dxf]
2022-04-26 ♻️ - Update PCB with new graphics. Create a light version of tenting puck with less details (silkscreen, ...). Bump to V0.3
    [ptechinos.kicad_sch]
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2022-05-05 ✨ ✅ - Setup board requirements to be manufactured by Jlcpcb and generated gerbers. Gerbers are valid and can be read without any error by different online viewer and the Kicad one.
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2022-05-08 🍱 🚚 - Move outputs file for V0.3 to proper folder in preparation for v0.4.
    [bottom_plate.dxf, bottom_plate_cut.dxf, keycaps.dxf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]
2022-05-08 ♻️ ✨ - More descriptive logo names (schema). Add board name to PCB.
    [ptechinos.kicad_sch]
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2022-05-14 ♻️ - Update PCB and schema with new drawing / board name. Update project date to today.
    [ptechinos.kicad_sch]
2022-05-14 🍱 ✨ 🚚 🔥 - Split old ouputs to v0.3. Generate v0.4 ouputs including STL/SVG files of plates, gerber preview in different colors, assembly preview. Clean inputs by removing obsolote files and adding ne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
    [bottom_plate.dxf, bottom_plate_10.dxf, bottom_plate_10_3mm.stl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]
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2022-05-15 🍱 🐛 - Correct flying friends drawing and clean unused graphics. Correct board name (petchinos to ptechinos).
2022-05-15 🐛 💄 - Implement drawing / text correction to footprints. See #5388ce217451fca6bf0010363cad309f8bcea6ce. Improve silkscreen graphics position and adjust copper lines to maximize free area.
    [ptechinos.kicad_sch]
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2022-05-24 ♻️ [Kicad] - Update PCB cutout and plates drawing (bottom/top/keycaps) based on ergogen config. Still required to move switches accordingly.
    [bottom_plate.dxf, bottom_plate_3mm.stl, keycaps.dxf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]
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2022-05-24 🔧 [Kicad] - Update board constraints for min clearance (0.1 to 0.15).
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2022-07-04 🚚 🔥 ♿️ - Re-organize project data to be more practical and as close as possible between versions.
    [bottom_plate.dxf, bottom_plate_10.dxf, bottom_plate_10_3mm.stl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]
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2022-07-10 ✨ - Update case / PCB generator configuration. Add choc spacing but with 1mm space between each keys. Add space to be able to place new component (Cirque trackpad). Reduce thumbs shift a little (redu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
    [ptechinos.yaml]
2022-07-10 ✨ 🚧 - Update electric schema and PCB design to add support for Cirque trackpad. Clean / Improve routing. Still require some checks before being marked as completed. 1x12 connectors is still in early 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
    [ptechinos.kicad_sch]
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2022-07-16 ✨ 🚧 - Update electric schema and PCB design to add support for both OLED and Cirque trackpad. Currently I2C connections are still pending but some space was created at the bottom of MCU.
    [ptechinos.kicad_sch]
2022-07-16 🐛 - Fix pg1350-EVQWGD001_R footprint. Pad labels should match.
2022-07-16 ✨ 🚧 - OLED and Trackpad are connected. VCC can now be cut to avoid losing power (bluetooth MCU without a way to cut the VCC line). Still some issues with uconnected items on the FPC connector (the on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
    [ptechinos.kicad_sch]
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2022-07-16 ✨ - Complete implementation of both OLED and Cirque trackpad. Clean trace and fix all errors / warnings about unconnected items. Mark unused pad on the FPC connector as unused to silent (still report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
    [ptechinos.kicad_sch]
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2022-07-16 ✨ 🍱 - Generate DXF and STL for plates / PCB using Ergogen configuration for v0.6.
    [bottom_plate.dxf, bottom_plate.stl, keycaps.dxf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]
2022-07-16 ♻️ - Update graphics with 037c49f932acf47295d794dda306d303e24019a4. Update PCB and schema version and date for v0.6.
    [ptechinos.kicad_sch]
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2022-07-17 ✨ 🍱 - Add teardrops. Increase ground trace width using specific net settings (0.25 to 0.28mm). Improve guard holes positions.
    [preview.dxf]
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2022-07-18 🩹 🍱 - Fix yellow color reference. Update board previews.
2022-07-26 💥 - Move encoder from F5/F4 to D4/C6 to free common analog pins on both RP2040 and EliteC boards. Break QMK layout with v0.5.
    [ptechinos.kicad_sch]
2022-07-26 ♻️ - Replace rev with R in FPC connector footprint to follow other components naming convention.
2022-07-26 ♻️ - Update texts placements on FPC connector footprint. Now using Hirose FPC connector reversible footprint.
    [ptechinos.kicad_sch]
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2022-07-26 🩹 🍱 - Fix connection between controller and top plate for them to be perfectly aligned.
    [bottom_plate.dxf, bottom_plate.stl, pcb.dxf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]
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2022-07-28 ♻️ 🍱 - Bump PCB / Schematic date to today. Regenerate preview of schema.
    [ptechinos.kicad_sch]
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2022-08-06 ♻️ - Reduce thumbs rotation (20 --> 15) and add more space between thumbs keys (+5mm). Update top edge of PCB (aligned with MCU and TRRS). Force TRRS and MCU to protrude slightly. Add 1.5U keycaps fo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
    [keycap_15u.dxf, keycap_1u.dxf, ptechinos.kicad_sch]
2022-08-06 🍱 - Regenerate DXF / STL / SVG / PDF based on PCB changes.
    [bottom_plate.dxf, bottom_plate.stl, keycaps.dxf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]
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2022-08-06 ♻️ 🍱 📝 - Make more space for encoder / optional key for MX keycaps using a MX to Choc v1 adapter. Also allow more room for trackpad/screen top plate.
    [keycaps.dxf, preview.dxf, top_plate.dxf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]
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2022-08-08 ♻️ - Insure at least 3.8mm between optional key / encoder and thumbs home to avoid hitting it by error. Move up thumbs cluster up by 1.3mm to reduce delta between thumbs home and other fingers (easie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
    [ptechinos.yaml]
2022-08-08 🚧 - Adjust top plate to allow to move down the reset footprint and clear some space for the bottom right guard hole.
    [ptechinos.yaml]
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2022-08-12 ✨ 💥 🚧 - Add another position for the encoder / key. Adjust matrix accordingly. Note that encoder A/B lines are currently shared. Update both schematic and PCB to fit all. Adjust board to 62c46e3cfa2a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
    [ptechinos.kicad_sch]
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2022-08-12 ✨ 💥 - Add an optimal position for encoder. Add top encoder cutout to top plate. Adjust holes accordingly.
    [bottom_plate.dxf, bottom_plate.stl, keycaps.dxf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]
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2022-08-14 ✨ 💥 - Both encoders (top and thumbs) are now using distinct pins.
    [ptechinos.kicad_sch]
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2022-08-20 ♻️ 🍱 - Correct position and size of encoder exclude for the top plate.
    [keycaps.dxf, preview.dxf, top_plate.dxf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]
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2022-08-20 ♻️ - Add new DXF (keycaps, preview, top_plate). Clean routing: avoid angle lower than 90°, put track above the bottom silkscreen (above the lower hole of the puck), make straight lines when possible.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
2022-08-26 ♻️ 🍱 - Add note about how to connect an SPI component.
    [ptechinos.kicad_sch]
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2022-08-30 🐛 🍱 - Move FFC connector further away from the PCB side to clear some space for the FFC Jumper Cables rigid part (required for unibody case).
    [bottom_plate.dxf, keycaps.dxf, pcb.dxf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]
2022-09-03 ♻️ 🚧 - Update components organization around the MCU to make some place for a pogo 4 pins connector. This connector is an alternative of TRRS to connect both halves together. This connection is safer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
    [ptechinos.kicad_sch]
2022-09-03 ♻️ - Revert MCU/thumbs corner increased horizontal space (1fce5ec6171882aaf4b7d512d2f85e93d4ed2eeb).
    [ptechinos.yaml]
2022-09-04 ♻️ 🍱 - Regenerate gerbers and assembly preview.- Lower the interface between MCU part and thumbs part to make some place for both Pogo and Reset. Improve corner line to avoid a small bump. Move guard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
    [bottom_plate.dxf, keycaps.dxf, pcb.dxf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]
2022-09-04 ♻️ 💄 - More via for the ground plane to reduce path to MCU ground pin. Better position for jumpers (OLED) centered on the trackpad FPC connector. Note that errors due to overlapping of both courtyard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
2022-09-04 ♻️ - Move Reset under the Trackpad to free space for pogo magnetic connectors. Update pogo schematic pins assignation to make it compatible with 3 pins pogo as well (used pins are now 1, 2, 3).
    [ptechinos.kicad_sch]
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2022-09-09 ✨ - Add smaller switch for reset. Allow to put it on the back side and make some place for pogo connectors.
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2022-09-09 ✨ ♻️ - Add footprint for pogo connectors. Add SPI header pins 1.27mm pitch (used for trackball component). Update I2C resistors position (now below the MCU board on the other side). Replace reset swi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
    [ptechinos.kicad_sch]
2022-09-09 📝 - Update keyboard features. Add/Update TODO tasks. Correct typos/grammar. Add missing parts to buy.
2022-09-09 ♻️ 💄 - Remove redundant header pins (battery). Adjust SPI headers to let enough place for horizontal ones. Clean schematics and make some space to add notes about SPI, I2C, USART Half-duplex.
    [ptechinos.kicad_sch]
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2022-09-11 ♻️ - Add more space around OLED pads. Pass DRC checks and verify ground plane. Add teardrops. Update DXF. Checks spacing for Qwiic/FFC and FFC/FFC jumper cable. Checks USB and TRRS top alignment.
    [ptechinos.kicad_sch]
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2022-09-17 ✨ - Move pogo connectors to the thumbs region. Replace 2x4 connector with a 1x8 connector (trackball).
    [ptechinos.kicad_sch]
2022-09-17 ♻️ 💥 🚧 - Clean ergogen configuration (removing hacks and rounded version of intermediary elements). Update keys spacing to match a real 1mm between caps (previously spacing was used as reference lead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
    [ptechinos.yaml]
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2022-09-18 ♻️ 💥 🚧 - Complete refactoring of the board. Clean lines, improve ground plane, let some place for trackball / pogo, let more place between trackpad and top plate. Update holes position (see .yaml). U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
2022-10-04 ♻️ - Clean module line connections especially at the top right (MCU).
    [bottom_plate.dxf, bottom_plate.stl, keycaps.dxf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]
2022-10-04 🩹 - Fixes footprint for PMW3360 sensor breakout board. Based on OGEN board.
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2022-10-04 ♻️ - Replace 2.2mm pogo with 2.54 ones. Add JST SH connectors (8 pins, vertical) on both sides to connect SPI lines to trackball.
    [ptechinos.kicad_sch]
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2022-10-09 💄 - Update MCU board silkscreen with correct labels. Clean ground fill. Add last preview layer. Remove old layer (was used as a reference).
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2022-10-15 ♻️ - Update copper line layout to fit SMD battery switch below the MCU board.
    [ptechinos.kicad_sch]
2022-10-18 📝 - Adding references for JST PH connectors and SMD power switch (replace through hole one in v0.66 branch).
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2022-10-20 ♻️ - Switch reset and battery JST in order to improve routing and ground plane connections. Avoid copper line to overlap with parallel silkscreen (right side of MCU board). Remove bat+ line at the to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
2022-11-19 🐛 ✨ - Correct layer assignation on the top side (some text was in solder mask an a pad was missing). Add 3D model.
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2022-12-03 🩹 - Add missing F.Paste pads on SMD on/off switch.
